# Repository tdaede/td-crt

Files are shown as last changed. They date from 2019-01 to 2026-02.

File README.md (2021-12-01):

# td-crt

This repo contains work-in-progress electronics to control a CRT monitor (aka a CRT chassis).

It is divided up into several separate projects, as follows:

* **[td-deflect](td-deflect/)** - Main PCB, containing microcontroller, horizontal and vertical deflection circuits, RGB amplifier, B+ power supply, 12V and -12V power supplies, and heater power supply. Functional with an enormous amount of rework.

* **[td-hv](td-hv/)** - Regulated HV/focus/screen power supply, based on K7000 clone flyback. Currently marginally functional, demos were done with the original monitor's HV.

* **[td-rgbinput](td-rgbinput/)** - Poorly named RGB amplifier that replaces the version on td-deflect, using more modern parts. Currently untested.

* **[td-180v](td-180v/)** - 180V (and heater) boost converter, designed to be installed on a neck board to provide an optional dedicated power supply for the cathode amplifiers.

* **[td-rgb](td-rgb/)** - Old RGB mod PCB, I should move it to a separate repo at some point.

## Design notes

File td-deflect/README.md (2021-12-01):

**td-deflect** is the primary PCB of td-crt, containing most of the pieces of a complete chassis.

The chassis is a multisync design with separate HV and deflection, allowing arbitrary scan rates, within the voltage and current limits of the ciruit.

RGB input
---------

There is a completely analog RGB path, based on a M51387P RGB amplifier IC. While effective, the chip has been out of production for a long time and therefore the **td-rgbinput** board exists as a future design that eliminates the IC.

Sync processing
---------------

The sync is separated by a LMH1980 sync separator IC. This is responsible for AC coupling the sync input, and separating it into separate H and V syncs (in the case of composite sync). It is also relied on for the back porch output, which is fed in to the clamping circuts, and the odd/even output, which is used for interlacing support.

Horizontal PLL
--------------

There is no analog horizontal PLL - instead, the horizontal sync is fed directly into the timers of the STM32F7. A software PLL is implemented using the internal timers. While this leads to quite robust sync processing, it also results in a minimum PLL jitter of a single clock period of 4.6ns. This is adequate for 15kHz content but not ideal. A future board may use the STM32G4 instead, which has an internal DLL that leads to minimum jitter on the order of 184ps.

Vertical ramp generator
-----------------------

The vertical ramp is generated in software. A software correction is applied for linearity, after which it is output via the stm32's DAC.

Vertical amplifier
------------------

The vertical amplifier is a classic discrete class AB amp, with current feedback (a voltage input corresponds to a current setpoint). The feedback network is fixed in analog components, which turns out not to be flexible enough for all yoke designs. In addition, it does not actually have any AB biasing, instead relying on feedback to avoid crossover distortion, which limits its performance. That said, it's quite effective as is. The amplifer is DC-coupled so that vertical position offsets are simply a DC bias on the input.

One leg of the amplifier is powered by 12V, and the other is powered by 48V in order to provide a faster retrace interval with high inductance yokes.

A planned future design replaces the vertical amplifier with a class D circuit with software feedback, to allow software tuning of the feedback network as well as increased power efficiency, though with the added complexity of dampled RLC output filter design.

Horizontal circuit
------------------

The horizontal circuit is a classic CRT horizontal class-C amplifier, which recovers the energy stored in the yoke for retrace.

The horizontal output transistor is a silicon carbide MOSFET for its very high voltage handling abilities. BJT-based HOTs are still manufactured as a backup option, however SiC MOSFETs are actually cheaper now and offer better performance. In addition, their intrinisic body diode renders an external freewheeling diode unnecessary.

A fixed film cap is used as the retrace timing capacitor.

There is a bank of 4 switchable S-capacitors allowing for 16 total possible S correction values.

There is no E-W correction or horizontal DC bias adjustment.

There is a current sense transformer provided for current feedback, but it is currently untested.

B+ power supply
---------------

The B+ power supply is a 100-200V boost converter to power the horizontal deflection circuits. It is based on a LT3758A asynchronous boost controller and is capable of up to 500mA of output current. It is currently thermally limited and could use a bit of work to increase efficiency and therefore boost the output power.

12V power supply
----------------

There is a 12V buck converter for 12V.

Negative 12V power supply
-----------------

There is a boost topology -12V converter. It currently does not work.

Heater power supply
-------------------

A linear regulator provides a heater power supply. Untested.

HV circuit
----------

Part of an extremely basic HV driver is present on the PCB, but is untested.

Software
--------

The on-board STM32 handles horizontal and vertical deflection, though the rest of the board runs without software intervention. The software is based on the [RTIC](https://rtic.rs) framework and written in Rust. It provides a very primitive serial interface to upload configuration and download runtime statistics. The software is also responsible for implementing all of the self protection logic.

There is a companion desktop GTK4 app with an extremely basic "remote" GUI.

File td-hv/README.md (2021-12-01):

**td-hv** is a HV/EHT driver board. It uses a K7000 clone replacement flyback (053X0528-001).

The circuit is a classic current mode flyback driver circuit based on the UCC3801. The circuit integrates secondary-side feedback by (ab)using the resistive divider created by the focus and screen potentiometers of the flyback, inspired by the drive circuit on the MS-2931 and similar monitors.

The primary drive transistor is a SiC MOSFET which has a sufficiently low gate drive voltage to be driven directly by the 12V gate drive output of the UCC3801.

The circuit free-runs at 14kHz, but can by synchronized to a higher frequency with a sync input pin, which is critical for not having a jittery iamge.

The circuit is currently very unstable. The primary problem is that the enormous amount of leakage inductance and capacitance of the flyback causes very slow ringing of the primary current. If the duty cycle and frequency of the switching circuit turn on the MOSFET while the switching node is at a high voltage (e.g. more than 100V) the sudden amount of current produces a voltage spike that confuses the current mode sensing of the UCC3801. Series LR damping has proven only marginally effective.

There is also an X-Ray protection circuit which provides a redundant shutdown path by measuring the peak voltage off a tertiary winding of the flyback.

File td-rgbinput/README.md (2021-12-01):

**td-rgbinput** is a replacement RGB analog path, providing the color controls between the RGB input and the final amplification stage on the neck board of the CRT.

Most consumer sets use an integrated RGB amplification IC, however none of these are still in production. Thus, this PCB was designed to instead use modern discrete amplifier components.

The primary challenge of the board is providing the global gain control across all 3 channels. This requires a voltage controlled amplifier, which is a difficult circuit to create when cross channel matching is desired.

The first stage of the input is AC coupling followed by a dc restore circuit, implemented as a clamp to ground. This is less accurate than a dc restore based on an op amp adder, but super simple to implement.

Next, the global gain control is applied via an AD8337 voltage controlled amplifier. The global gain voltage is divided by a per-channel gain adjustment before being fed into the AD8337's gain input.

Following this, a global and per-channel bias is applied via a resistor adder. The global bias voltage is carefully buffered to avoid compromising the high frequency response of the circut. In addition, a blanking input can pull the output voltage down to zero at this stage.

Finally, an amplfiication stage based on the ADA4861 provides a fixed 2x gain, and more importantly, higher current to the output. The outputs include a series 47 ohm resistor with the assumption that they will go directly to the base of transistors on the neck board.

The circuit also has a local 5V supply, -5V supply, and a blank OR-ing circuit for convenience. Termination can be enabled or disabled via a bank of DIP switches.

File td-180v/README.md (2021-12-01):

td-180v is a power supply designed to bolt on the back of a Nanao MS9 neck board and provide the cathode amplifier and heater voltages, independent of the B+ regulation of the main PCB. It also provides an optional linear regulator for the heater.

It is a simple asynchronous boost converter design based on the (relatively expensive) LT3758A. It is powered by the B+ rail input, and also requires a +12V rail for logic. As a result it can only regulate to voltages higher than B+.

The current design is too noisy for practical use.

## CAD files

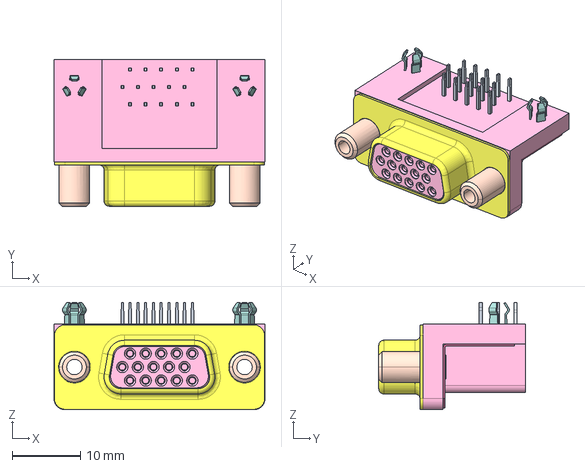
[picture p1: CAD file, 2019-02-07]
td-rgb/amphenol/iicd15s13e6gv00lf.igs
31.0 x 21.6 x 15.8 mm

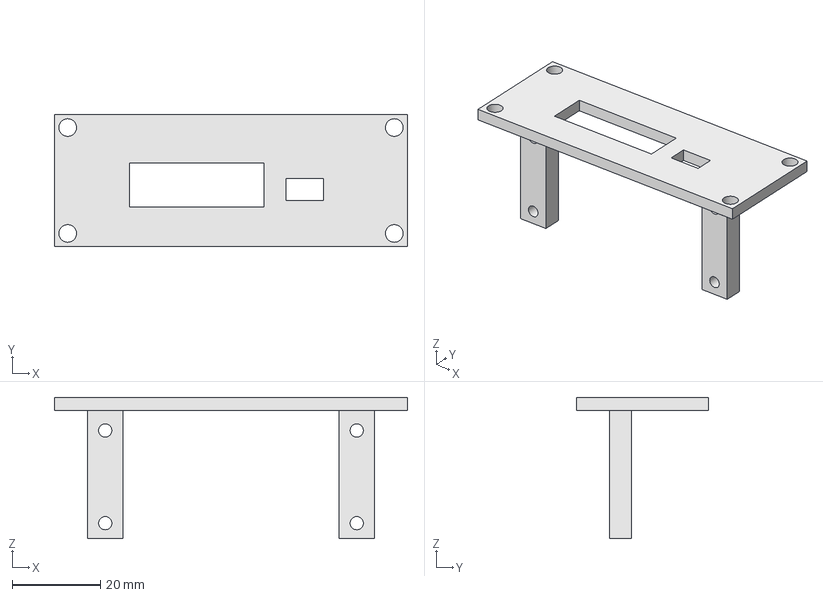
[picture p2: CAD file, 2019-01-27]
td-rgb/td-rgb-bracket.fcstd
80.0 x 30.0 x 32.0 mm

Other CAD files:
td-rgb/td-rgb-bracket.stl

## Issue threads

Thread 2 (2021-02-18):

I can't open the td-deflect.kicad_pcb with kicad 5.1.9

maxxsun, 2021-02-18:
I can't open the td-deflect.kicad_pcb with kicad 5.1.9 .

tdaede, 2021-08-14:
You need KiCad nightly to open it.

(the other PCBs use stable)

Closed 2021-08-14.

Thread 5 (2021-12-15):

Can this drive a JVC bubble tube A68ADT25X01?

chuckhacker, 2021-12-15:
JVC’s curved bubble tube, the A68ADT25X01, was used for 10 years throughout their consumer TV lines.

The tube was used so long by JVC because of its great design. Even TVs from 20 years ago have no geometry issues and very minor focus issues. The quality is superb. At this point, it is easier to come across the tube than an actual D-Series TV, as prices continue to inflate.

So if it's possible to come up with an open source driver board for this CRT tube, it would certainly fill a niche for enthusiasts like myself.

tdaede, 2021-12-18:
Yes, it should be able to. That tube (and the equivalent Toshiba models used for MS8/MS9 etc) should work well. The circuit is designed to use the original yoke, so if the yoke is bonded it should still be OK.

Depending on the particular inductance of the yoke, higher scan rates (24-31kHz) can be more difficult, though if it's not more than the ~2mH that most of these are it should be OK.

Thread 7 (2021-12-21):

Can this drive Phillips A59EAK552X21 ?

oomek, 2021-12-21:
It's a tube used in Bang & Olufsen Beovision 1 consumer TV. It has no convergence rings and 6 pin yoke.
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

oomek, 2021-12-21:
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

tdaede, 2021-12-21:
That looks pretty typical. It can't currently drive the rotation coil so you won't have rotation adjustment.

The neck board transistors look surprisingly small. Is a service manual available?

oomek, 2021-12-22:
Oh, so this 2 wires aren't required to drive the yoke, just are responsible for rotation? I don't have any schematic, just manual which is'n very helpful. I could make some more photos of the transistors.

riggles1, 2022-07-14:
Great to know, as LG.Philips are very common here in Europe, used my multiple brands and arcade machines using these tubes as well. Usually these yokes have an electromagnetic convergence piece, and the tube themselves have dual focus (dual focus tubes are pretty much the norm in Europe regardless of manufacturer for 25-29" (A59-A66) tube sizes).

Relieving to know these won't be problematic, with how common they are in these regions.

oomek, 2022-07-14:
Update: I've opened today another Beovision1, an older SW 1.2 version and it has only 4 wires connected to the deflection coils. Red and Brown are NC.

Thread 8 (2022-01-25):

A question about the 2N7002NXBKR Trench MOSFET

soniccd123, 2022-01-25:
Hello friend,

Great project, looking forward to the next developments, would love to use some of it in one of my TVs someday

I have a question. For the last year and a half i've been working on a Panasonic TC-14RM15L as a test bed for some modifications with the objective of creating a adequate and safe way to add RGB inputs to non European CRT TVs. There are ways to do it in older TVs that have the Jungle IC separated from the TV MCU, but most modern CRTs do not have this configuration.

One area that I'm having trouble is the HBlanking on this set, without correct color signal atenuation, lots of regularly timed transversal lines are visible on the screen. These lines seem to be the beam returning to draw the next line. The problem is that some devices, like the Sega Dreamcast, in specific video modes, will display these lines even with the needed atenuation. Looking at you schematics I supose that I need to pull each color signal low every blank interval and maybe these lines will disapear. I'm excited to try your solution (from what i could understand in the schematics), but I need to know if the 2N7002NXBKR is strictly necessary or one could use more acessible alternatives like the 2N7002L.

Thank you very much, good work!

tdaede, 2022-01-25:
Hi,

Yes, you can use a plain old 2N7002. The exact one I used is just a particular manufacturer's model that I chose at the time based on availability.

There are two RGB circuits in this repo - one is on td-deflect, and one is in td-rgbinput. The td-deflect one is older and works well, but uses an old stock IC. The td-rgbinput one is functionally similar but built with discrete components.

The td-rgbinput circuit has 4 separate functionalities - a DC restore circuit for AC coupled inputs, a blanking circiut, a gain control circuit, and a bias circuit. You might not need all these parts depending on where you're inserting the signal.

soniccd123, 2022-01-25:
I'm gonna take a look and try to implement them to test, I'm connecting directly to the neckboard of the TV, more specifically, to the video output amplifier that drives the cathodes (TDA6107AJFN1), i'm connecting just the RGB signals to it and letting the TV's circuitry take charge of the Sync. Between the neckboard and the device I've added some simple circuitry to control the signals, but not nearly as elegant as your aproach. It works quite well, this TV actually became my main way to play old video games, but I think that its possible to make it even better adapting your designs to it.

Do you recommend any resources to learn more about TVs and analog electronics? While i've been playing around with this TV, i lack a lot of the knowledge to really understand deeply how all of these parts work

tdaede, 2022-01-25:
The neck board on that TV actually has a blanking input, I think. If you
supply an appropriately timed blanking signal (might even just be able to
use the sync signal to start with) you should be able to make it blank.

Unfortunately a lot of this knowledge is pre-internet. I'd recommend Sam's
FAQs to start:

https://www.repairfaq.org/sam/tvfaq.htm
https://www.repairfaq.org/sam/monfaq.htm
https://www.repairfaq.org/sam/crtfaq.htm
https://www.repairfaq.org/sam/deflfaq.htm

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

soniccd123, 2022-01-26:
Thanks for the resources, it is quite hard indeed to find these things on internet

Was taking a look at the TV service manual, unfortunately the neck board doesn't seem to have a blanking input, it does have a AKB output from the video amplifier that drives the cathodes, but I suspect to me that the blanking is done on the MCU/Jungle chip before this step (TDA11115NDS, a chip which not datasheet could be found).

I took a look at the td-deflect board and saw that you used a M51387P as video amplifier which i found pretty interesting, not that I didn't like your discrete aproach, but the M51387P seems to be quite cheap where I live. This amplifier is suposed to be used to drive tube directly? In the case of my TV that uses a TDA6107AJFN1 to drive the tube, should the M51387P outputs drive this amplifier or the tube directly?

tdaede, 2022-01-26:
The outputs should drive the amplifier.

I think that the AKB signal is actually an input to the amplifier, not an output.

soniccd123, 2022-01-27:
Are you sure? I found the amplifier datasheet, from what I understood, AKB is connected to the amplifier pin 5 which is a "black-current measurement output" in the datasheet words. It would be very helpful if it was the blank signal input.

tdaede, 2022-01-27:
No, not sure. Didn't realize a monitor like this would bother measuring that, but I suppose it could.

soniccd123, 2022-03-16:
Hey, the M51387P finally arrived, i'm taking a look at the TV schematics and signals, having a hard time to find how to extract the blanking signal from sync. I see that it is very similar to H-sync, can i use it or do i need another solution?

tdaede, 2022-06-27:
Yes, you can use H-sync to blank. However, clamping needs to not intersect with blanking - it needs to happen after blanking.

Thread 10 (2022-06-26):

Suggestions for someone who wants to try this project

8lall0, 2022-06-26:
Hi,
i have a perfect trinitron that i can "sacrifice" to test this project. How can i start with it? Is there a bom and pcbs?

Thanks!

8lall0, 2022-06-29:
@tdaede oh ok, thank you! :)
I hope this project will continue, it's so interesting.

Closing the issue :)

Closed 2022-06-29.

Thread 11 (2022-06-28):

Question- drivable tubes

michaellarson1000, 2022-06-28:
Would it be possible to drive tubes such as vga monitor tubes or hd crt 1080i tubes with this board, given that suitable parts are used?

tdaede, 2022-07-06:
I can't make any guarantees right now. It will work on trinitrons with appropriate wiring. The main difficulty is the yoke inductance and deflection sensitivity, which you can't know without getting the tube. There are workarounds even if it isn't ideal.

Numbski, 2022-07-06:
Oh, by all means - not looking for any kind of guarantee, and this is all very much WIP.

My question was more one of "am I even barking up a feasible tree"?

It sounds as though "yes, it might be, but we have no certainty".

I will see if I can run down a service manual and figure out what tube is in play on this one in particular.  Last I can do to put this to bed, but this does add a small amount of clarity.

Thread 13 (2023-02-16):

voltages for contrast and brightness SW controlled?

gcopoix, 2023-02-16:
Hi, what about controlling the voltages for contrast and brightness by e.g. an 8ch I2C/SPI DAC?
Would have several advantages in my opinion:
- less effort for populating the PCB
- less footprint, smaller PCB
- could  lead to better profiles for known CRTs
- all SW controllable (without disassembling the Monitor/TV)
- cheaper (e.g. an DAC088S085 is around 3...4 USD) ?

The other resistors for voltage control could be handled this way too, or by a digital poti ?

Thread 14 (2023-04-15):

Can you generate schematic pdf

boilerbots, 2023-04-15:
It would be nice if you generated a PDF of the schematics when you upload the project. That would make it easy for people to look at without the hassle of KiCad. I am curios to take a look at your design, I have been working on driving electrostatic CRTs for vector clocks with modern HV MOSFETs and switching power supplies.

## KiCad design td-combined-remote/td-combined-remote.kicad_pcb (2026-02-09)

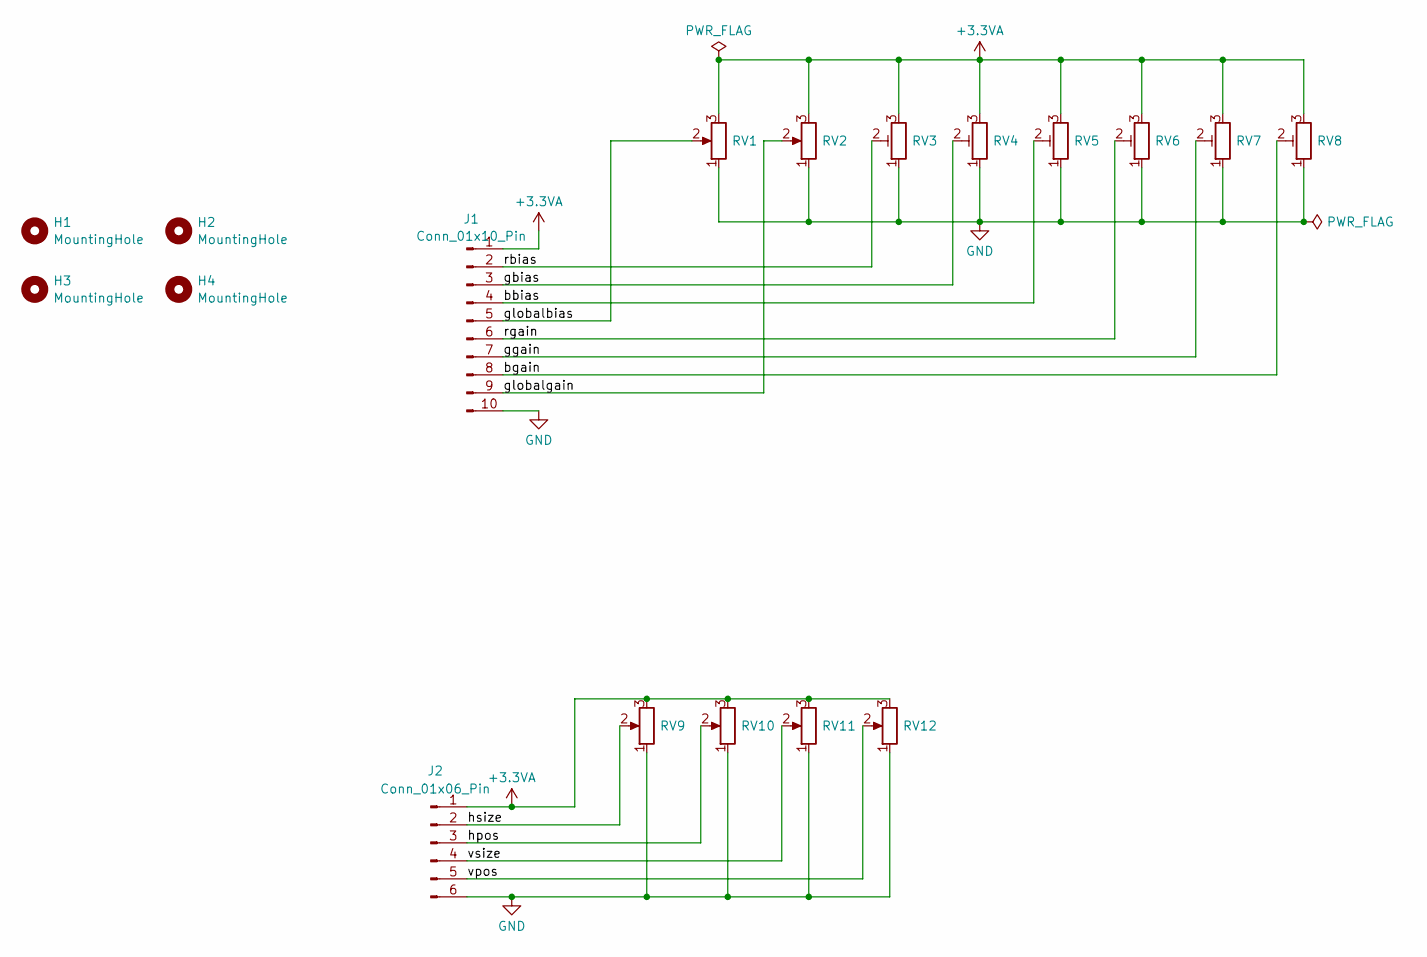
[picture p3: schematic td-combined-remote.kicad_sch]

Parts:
H1, H2, H3, H4: MountingHole; MountingHole_3.2mm_M3
J1: Conn_01x10_Pin; JST_XH_S10B-XH-A_1x10_P2.50mm_Horizontal; Digikey 455-S10B-XH-A-ND
J2: Conn_01x06_Pin; JST_XH_S6B-XH-A_1x06_P2.50mm_Horizontal; Digikey 455-S6B-XH-A-ND
RV1, RV2, RV9, RV10, RV11, RV12: R_Potentiometer; Potentiometer_Alps_RK09K_Single_Vertical; Digikey PTV09A-4015U-B103-ND
RV3, RV4, RV5, RV6, RV7, RV8: R_Potentiometer_Trim; Potentiometer_Bourns_3386P_Vertical; Digikey 3386P-103TLF-ND

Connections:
+3.3VA: J1.1, J2.1, RV1.3, RV2.3, RV3.3, RV4.3, RV5.3, RV6.3, RV7.3, RV8.3, RV9.3, RV10.3, RV11.3, RV12.3
/bbias: J1.4, RV5.2
/bgain: J1.8, RV8.2
/gbias: J1.3, RV4.2
/ggain: J1.7, RV7.2
/globalbias: J1.5, RV1.2
/globalgain: J1.9, RV2.2
/hpos: J2.3, RV10.2
/hsize: J2.2, RV9.2
/rbias: J1.2, RV3.2
/rgain: J1.6, RV6.2
/vpos: J2.5, RV12.2
/vsize: J2.4, RV11.2
GND: J1.10, J2.6, RV1.1, RV2.1, RV3.1, RV4.1, RV5.1, RV6.1, RV7.1, RV8.1, RV9.1, RV10.1, RV11.1, RV12.1

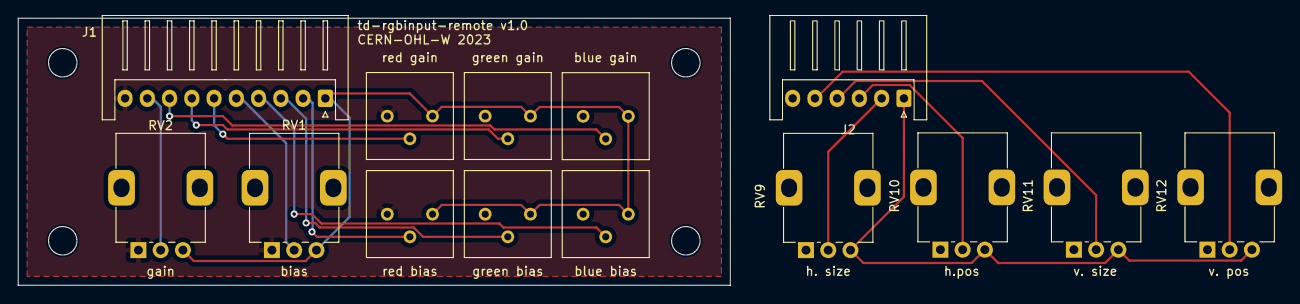
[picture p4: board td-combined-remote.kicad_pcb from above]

Board: 2 copper layers, 80.0 x 30.0 mm, 18 parts (0 on the bottom side), 14 nets.

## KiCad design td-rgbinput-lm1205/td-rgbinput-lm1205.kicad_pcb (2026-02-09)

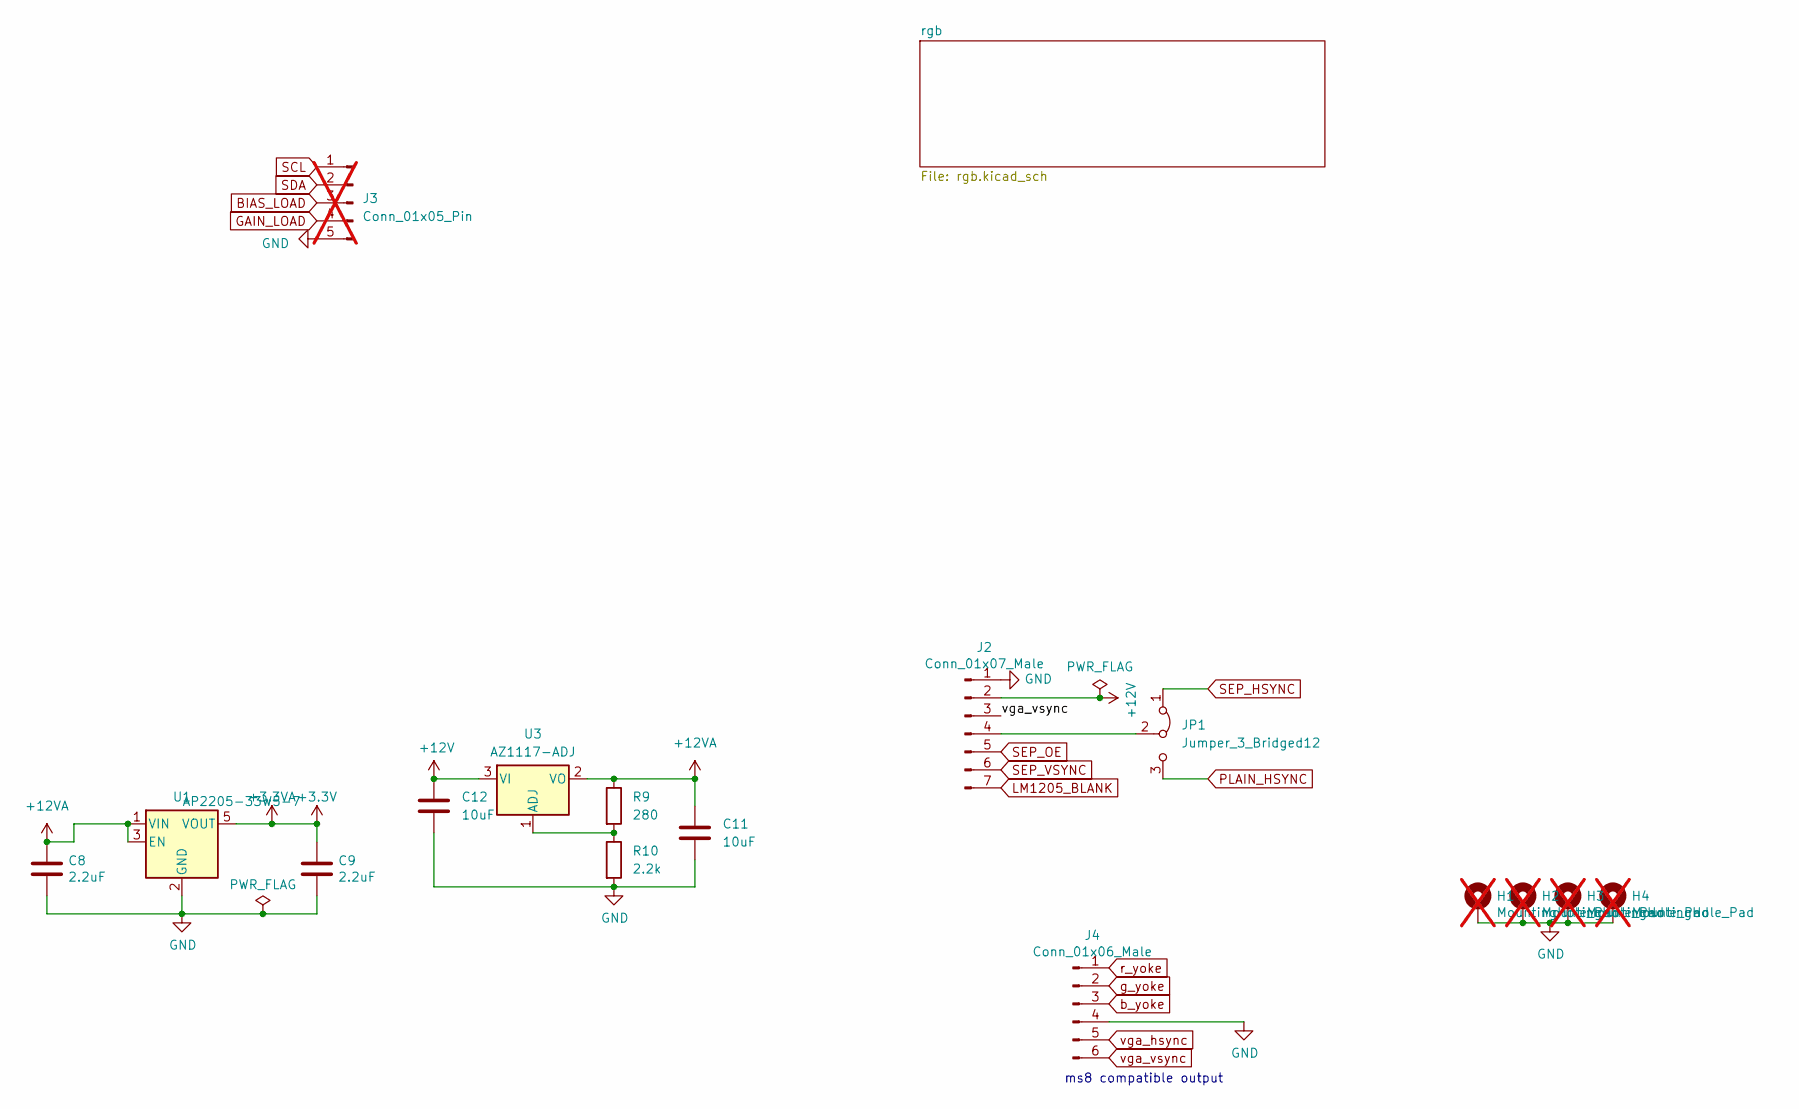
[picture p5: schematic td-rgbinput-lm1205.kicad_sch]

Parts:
C8, C9: 2.2uF; C_0805_2012Metric; Digikey 490-14467-1-ND
C11, C12: 10uF; C_0805_2012Metric
H1, H2, H3, H4: MountingHole_Pad; MountingHole_3.2mm_M3_Pad_Via; not fitted
J2: Conn_01x07_Male; JST_XH_B7B-XH-A_1x07_P2.50mm_Vertical; Digikey 1175-51025-07-0100-01-ND
J3: Conn_01x05_Pin; JST_XH_B5B-XH-A_1x05_P2.50mm_Vertical; Digikey B5B-XH-A; not fitted
J4: Conn_01x06_Male; JST_EH_B6B-EH-A_1x06_P2.50mm_Vertical; Digikey 455-1615-ND
JP1: Jumper_3_Bridged12; PinHeader_1x03_P2.54mm_Vertical
R9: 280; R_0805_2012Metric; Digikey 311-280CRCT-ND
R10: 2.2k; R_0805_2012Metric; Digikey 311-2.2KCRCT-ND
U1: AP2205-33W5-7; SOT-23-5; Digikey 31-AP2205-33W5-7CT-ND
U3: AZ1117-ADJ; SOT-223-3_TabPin2

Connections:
+3.3V: C9.1, U1.5 (VOUT); also elsewhere on the board
+12V: C12.1, J2.2, U3.3 (VI)
+12VA: C8.1, C11.1, R9.1, U1.1 (VIN), U1.3 (EN), U3.2 (VO); also elsewhere on the board
BIAS_LOAD: J3.3; also elsewhere on the board
GAIN_LOAD: J3.4; also elsewhere on the board
GND: C8.2, C9.2, C11.2, C12.2, H1.1, H2.1, H3.1, H4.1, J2.1, J3.5, J4.4, R10.2, U1.2 (GND); also elsewhere on the board
LM1205_BLANK: J2.7; also elsewhere on the board
unnamed: J2.4, JP1.2 (C)
unnamed: R9.2, R10.1, U3.1 (ADJ)
PLAIN_HSYNC: JP1.3 (B); also elsewhere on the board
SCL: J3.1; also elsewhere on the board
SDA: J3.2; also elsewhere on the board
SEP_HSYNC: JP1.1 (A); also elsewhere on the board
SEP_OE: J2.5; also elsewhere on the board
SEP_VSYNC: J2.6; also elsewhere on the board
b_yoke: J4.3; also elsewhere on the board
g_yoke: J4.2; also elsewhere on the board
r_yoke: J4.1; also elsewhere on the board
vga_hsync: J4.5; also elsewhere on the board
vga_vsync: J2.3, J4.6; also elsewhere on the board

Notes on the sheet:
ms8 compatible output

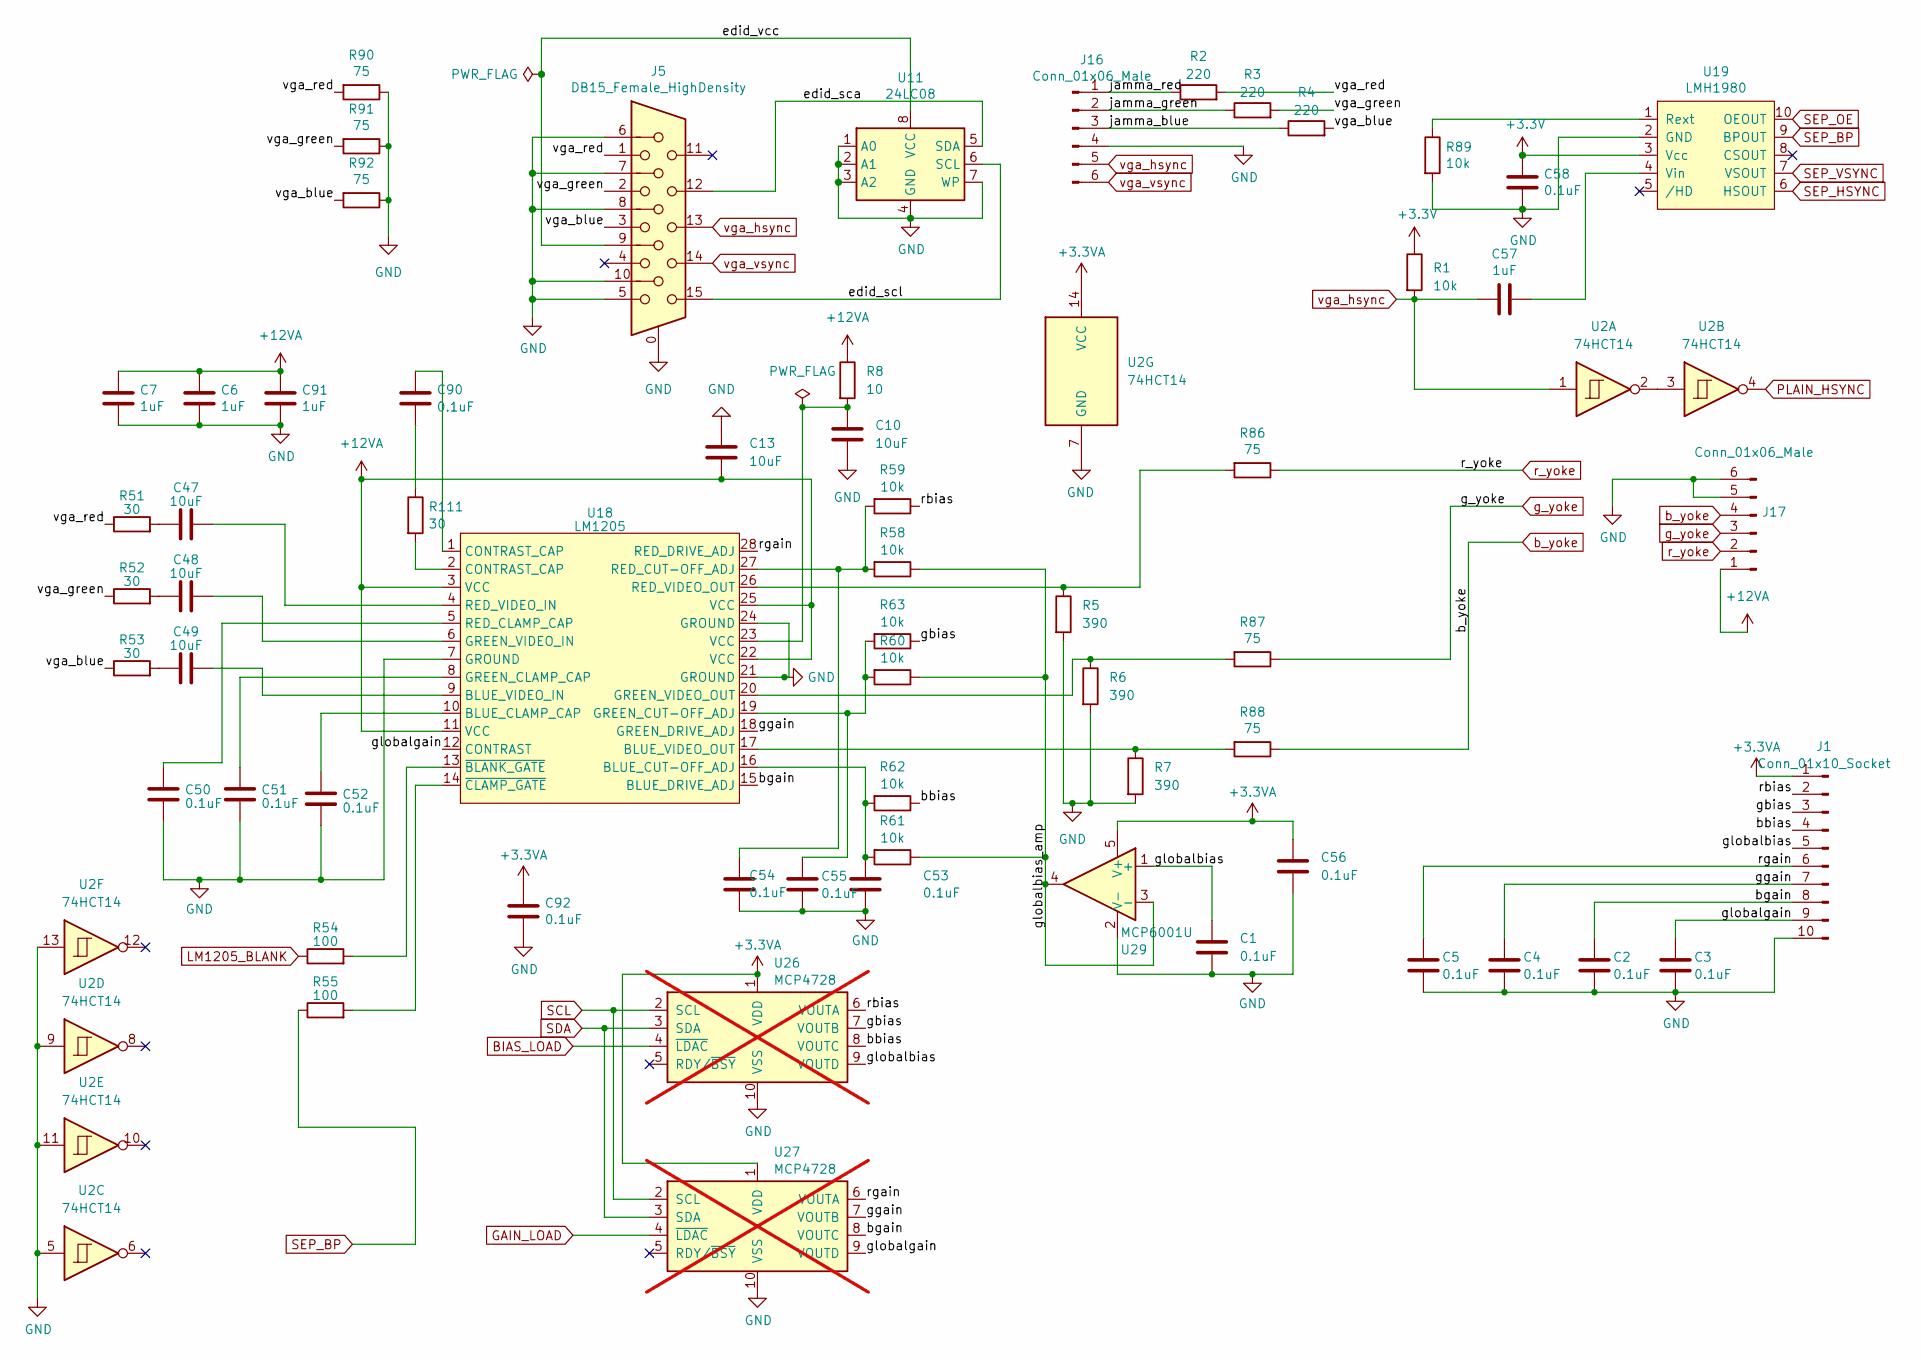
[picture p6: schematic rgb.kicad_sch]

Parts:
C1, C2, C3, C4, C5, C50, C51, C52, C53, C54, C55, C56, C58, C90, C92: 0.1uF; C_0805_2012Metric; Digikey 1276-1099-1-ND
C6, C7, C91: 1uF; C_0805_2012Metric; Digikey 1276-1066-1-ND
C10, C13: 10uF; C_0805_2012Metric
C47, C48, C49: 10uF; C_0805_2012Metric; Digikey 490-10516-1-ND
C57: 1uF; C_0805_2012Metric; Voltage 25V; Digikey 1276-1066-1-ND
J1: Conn_01x10_Socket; JST_XH_B10B-XH-A_1x10_P2.50mm_Vertical; Digikey 455-B10B-XH-A-ND
J5: DB15_Female_HighDensity; DSUB-15-HD_Socket_Horizontal_P2.29x2.54mm_EdgePinOffset8.35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; Digikey AE11024-ND
J16: Conn_01x06_Male; JST_EH_B6B-EH-A_1x06_P2.50mm_Vertical; Digikey 455-1615-ND
J17: Conn_01x06_Male; JST_XH_B6B-XH-A_1x06_P2.50mm_Vertical; Digikey 455-2271-ND
R1, R58, R59, R60, R61, R62, R63, R89: 10k; R_0805_2012Metric; Digikey 311-1.00KCRCT-ND
R2, R3, R4: 220; R_0805_2012Metric; Digikey 311-220CRCT-ND
R5, R6, R7: 390; R_0805_2012Metric
R8: 10; R_0805_2012Metric
R51, R52, R53, R111: 30; R_0805_2012Metric; Digikey 311-30.0CRCT-ND
R54, R55: 100; R_0805_2012Metric; Digikey 311-100CRCT-ND
R86, R87, R88, R90, R91, R92: 75; R_0805_2012Metric; Digikey 311-75.0CRCT-ND
U2: 74HCT14; SOIC-14_3.9x8.7mm_P1.27mm; Digikey 74HCT14S14-13DICT-ND
U11: 24LC08; SOIC-8_3.9x4.9mm_P1.27mm; Digikey 24LC08BT/SNCT-ND
U18: LM1205; DIP-28_W15.24mm
U19: LMH1980; VSSOP-10_3x3mm_P0.5mm; Digikey LMH1980MM/NOPBCT-ND
U26, U27: MCP4728; MSOP-10_3x3mm_P0.5mm; Digikey MCP4728T-E/UNCT-ND; not fitted
U29: MCP6001U; SOT-23-5; Digikey MCP6001UT-I/OTCT-ND

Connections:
+3.3V: C56.1, C58.1, C92.1, J1.1, R1.1, U2.14 (VCC), U19.3 (Vcc), U26.1 (VDD), U27.1 (VDD), U29.5 (V+); also elsewhere on the board
+12VA: C6.1, C7.1, C13.1, C91.1, J17.1, R8.1, U18.3 (VCC), U18.11 (VCC), U18.22 (VCC), U18.25 (VCC); also elsewhere on the board
/rgb/bbias: J1.4, R62.1, U26.8 (VOUTC)
/rgb/bgain: C2.1, J1.8, U18.15 (BLUE_DRIVE_ADJ), U27.8 (VOUTC)
/rgb/edid_sca: J5.12, U11.5 (SDA)
/rgb/edid_scl: J5.15, U11.6 (SCL)
/rgb/edid_vcc: J5.9, U11.8 (VCC)
/rgb/gbias: J1.3, R63.1, U26.7 (VOUTB)
/rgb/ggain: C4.1, J1.7, U18.18 (GREEN_DRIVE_ADJ), U27.7 (VOUTB)
/rgb/globalbias: C1.1, J1.5, U26.9 (VOUTD), U29.1 (+)
/rgb/globalbias_amp: R58.1, R60.1, R61.1, U29.3 (-), U29.4
/rgb/globalgain: C3.1, J1.9, U18.12 (CONTRAST), U27.9 (VOUTD)
/rgb/jamma_blue: J16.3, R4.1
/rgb/jamma_green: J16.2, R3.1
/rgb/jamma_red: J16.1, R2.1
/rgb/rbias: J1.2, R59.1, U26.6 (VOUTA)
/rgb/rgain: C5.1, J1.6, U18.28 (RED_DRIVE_ADJ), U27.6 (VOUTA)
/rgb/vga_blue: J5.3, R4.2, R53.1, R92.2
/rgb/vga_green: J5.2, R3.2, R52.1, R91.2
/rgb/vga_red: J5.1, R2.2, R51.1, R90.2
BIAS_LOAD: U26.4 (~LDAC); also elsewhere on the board
GAIN_LOAD: U27.4 (~LDAC); also elsewhere on the board
GND: C1.2, C2.2, C3.2, C4.2, C5.2, C6.2, C7.2, C10.2, C13.2, C50.1, C51.1, C52.1, C53.2, C54.2, C55.2, C56.2, C58.2, C91.2, C92.2, J1.10, J5.0, J5.5, J5.6, J5.7, J5.8, J5.10, J16.4, J17.5, J17.6, R5.2, R6.2, R7.2, R89.2, R90.1, R91.1, R92.1, U2.5, U2.7 (GND), U2.9, U2.11, U2.13, U11.1 (A0), U11.2 (A1), U11.3 (A2), U11.4 (GND), U11.7 (WP), U18.7 (GROUND), U18.21 (GROUND), U18.24 (GROUND), U19.2 (GND), U26.10 (VSS), U27.10 (VSS), U29.2 (V-); also elsewhere on the board
LM1205_BLANK: R54.1; also elsewhere on the board
unnamed: C10.1, R8.2, U18.23 (VCC)
unnamed: C47.1, R51.2
unnamed: C48.1, R52.2
unnamed: C49.1, R53.2
unnamed: C90.1, U18.1 (CONTRAST_CAP)
unnamed: C90.2, R111.1
unnamed: R111.2, U18.2 (CONTRAST_CAP)
unnamed: U2.2, U2.3
unnamed: C52.2, U18.10 (BLUE_CLAMP_CAP)
unnamed: C53.1, R61.2, R62.2, U18.16 (BLUE_CUT-OFF_ADJ)
unnamed: C49.2, U18.9 (BLUE_VIDEO_IN)
unnamed: R7.1, R88.2, U18.17 (BLUE_VIDEO_OUT)
unnamed: C51.2, U18.8 (GREEN_CLAMP_CAP)
unnamed: C55.1, R60.2, R63.2, U18.19 (GREEN_CUT-OFF_ADJ)
unnamed: C48.2, U18.6 (GREEN_VIDEO_IN)
unnamed: R6.1, R87.2, U18.20 (GREEN_VIDEO_OUT)
unnamed: C50.2, U18.5 (RED_CLAMP_CAP)
unnamed: C54.1, R58.2, R59.2, U18.27 (RED_CUT-OFF_ADJ)
unnamed: C47.2, U18.4 (RED_VIDEO_IN)
unnamed: R5.1, R86.2, U18.26 (RED_VIDEO_OUT)
unnamed: R54.2, U18.13 (~BLANK_GATE)
unnamed: R55.2, U18.14 (~CLAMP_GATE)
unnamed: R89.1, U19.1 (Rext)
unnamed: C57.1, U19.4 (Vin)
PLAIN_HSYNC: U2.4; also elsewhere on the board
SCL: U26.2 (SCL), U27.2 (SCL); also elsewhere on the board
SDA: U26.3 (SDA), U27.3 (SDA); also elsewhere on the board
SEP_BP: R55.1, U19.9 (BPOUT)
SEP_HSYNC: U19.6 (HSOUT); also elsewhere on the board
SEP_OE: U19.10 (OEOUT); also elsewhere on the board
SEP_VSYNC: U19.7 (VSOUT); also elsewhere on the board
b_yoke: J17.4, R88.1; also elsewhere on the board
g_yoke: J17.3, R87.1; also elsewhere on the board
r_yoke: J17.2, R86.1; also elsewhere on the board
vga_hsync: C57.2, J5.13, J16.5, R1.2, U2.1; also elsewhere on the board
vga_vsync: J5.14, J16.6; also elsewhere on the board

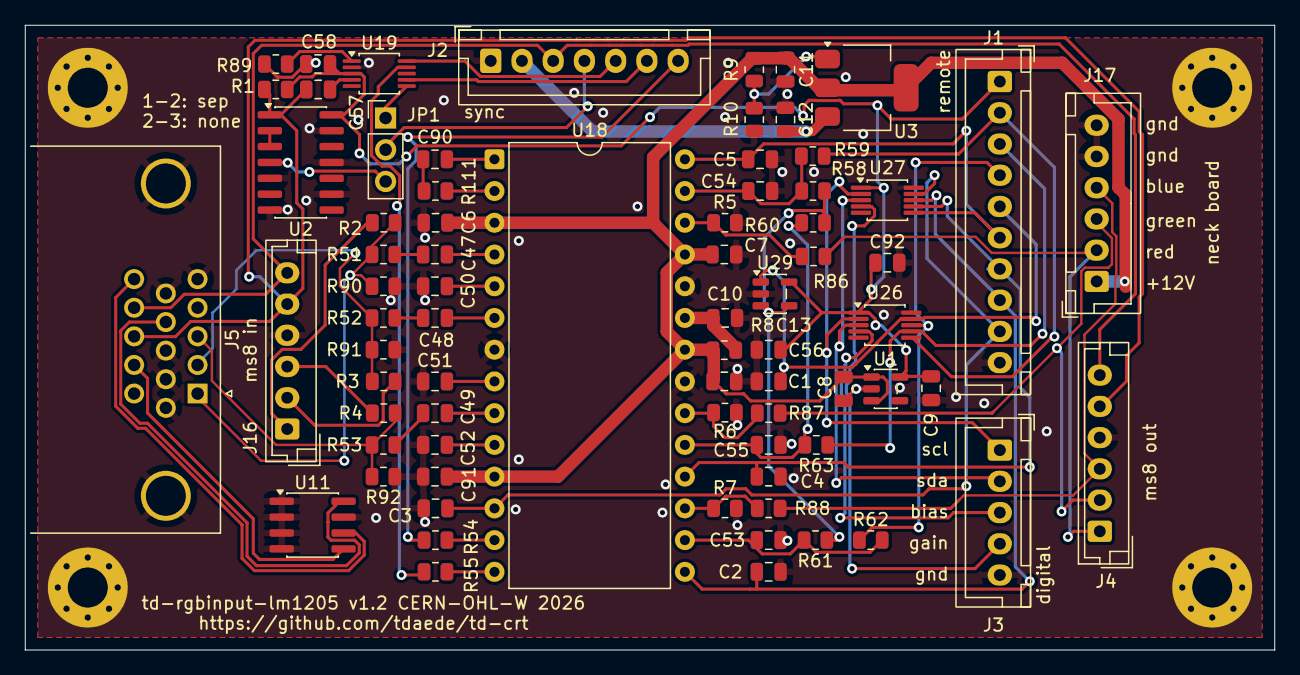
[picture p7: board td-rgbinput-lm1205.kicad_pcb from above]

Board: 2 copper layers, 100.0 x 50.0 mm, 78 parts (0 on the bottom side), 63 nets.

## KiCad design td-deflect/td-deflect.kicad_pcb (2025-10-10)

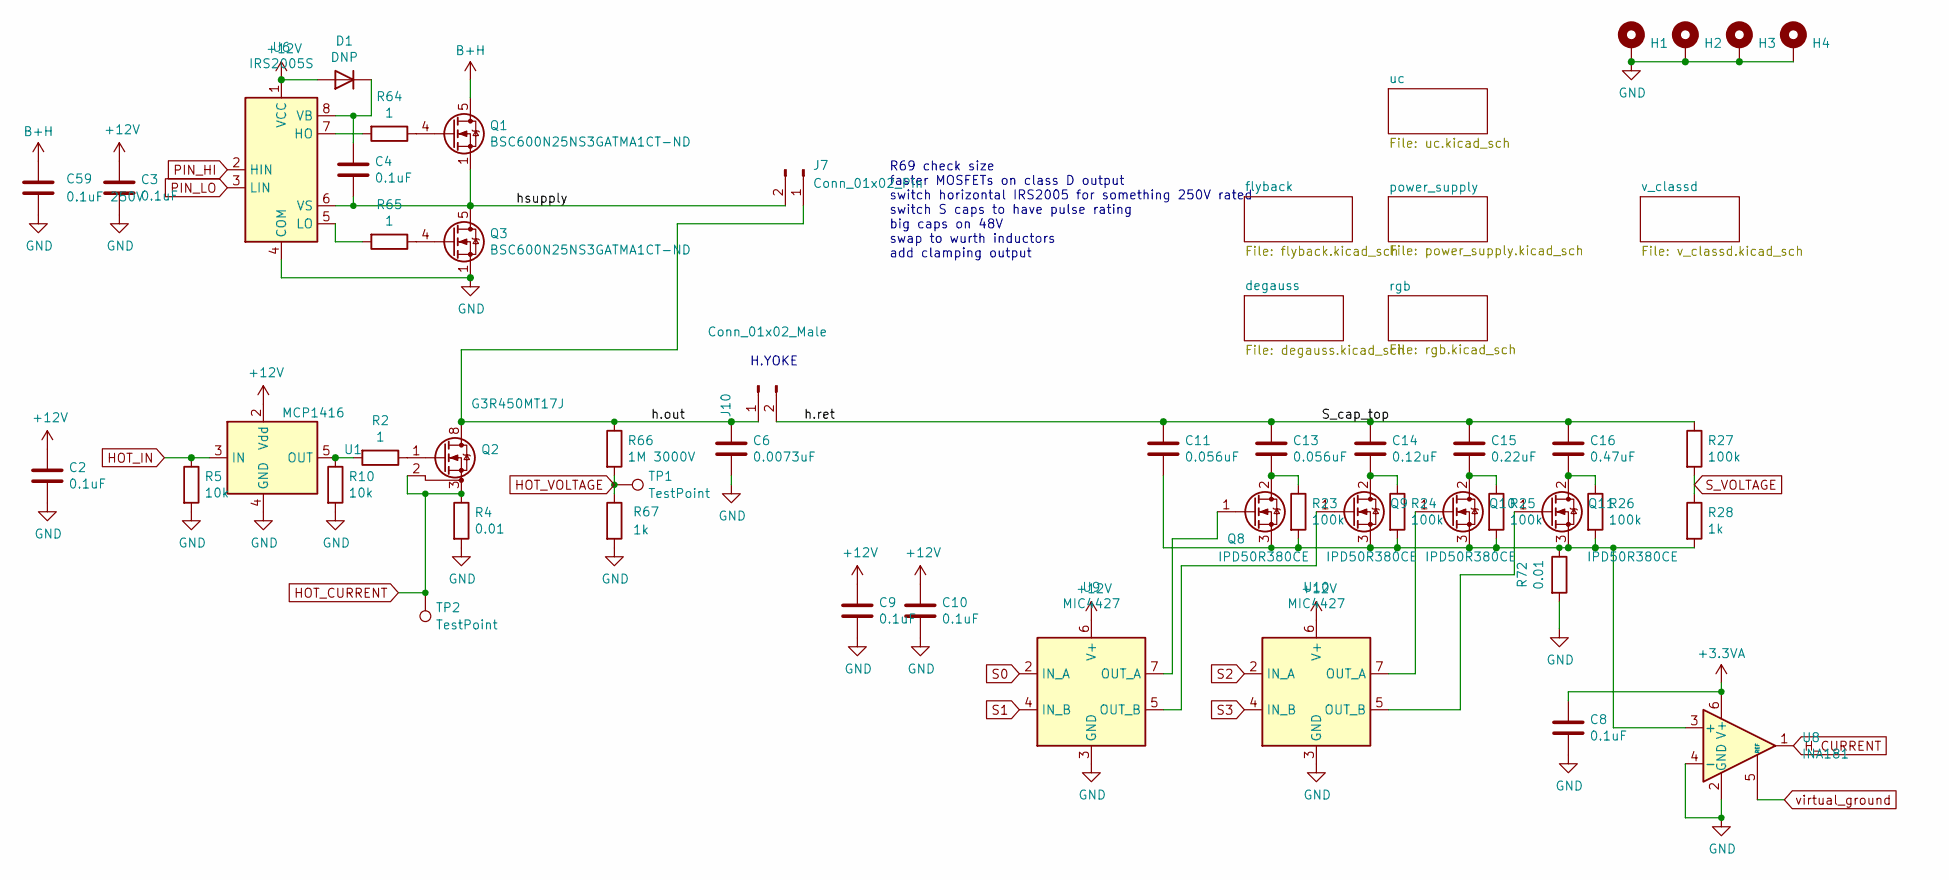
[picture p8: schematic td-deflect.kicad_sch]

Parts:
C2, C3, C4: 0.1uF; C_0805_2012Metric_Pad1.18x1.45mm_HandSolder; Digikey 311-1140-1-ND
C6: 0.0073uF; C_Rect_L18.0mm_W6.0mm_P15.00mm_FKS3_FKP3; Voltage 2000V; Digikey 495-3231-ND
C8, C9, C10: 0.1uF; C_0805_2012Metric_Pad1.18x1.45mm_HandSolder; Voltage 10V; Digikey 311-1140-1-ND
C11, C13: 0.056uF; C_Rect_L18.0mm_W5.0mm_P15.00mm_FKS3_FKP3; Voltage 250V; Digikey 732-5795-ND
C14: 0.12uF; C_Rect_L18.0mm_W8.0mm_P15.00mm_FKS3_FKP3; Voltage 250V; Digikey 732-5799-ND
C15: 0.22uF; C_Rect_L18.0mm_W6.0mm_P15.00mm_FKS3_FKP3; Voltage 250V; Digikey 732-5802-ND
C16: 0.47uF; C_Rect_L18.0mm_W8.0mm_P15.00mm_FKS3_FKP3; Voltage 250V; Digikey 732-5805-ND
C59: 0.1uF 250V; C_1206_3216Metric; Digikey 445-8899-1-ND
D1: DNP; D_SOD-123; Digikey ES1G-FDICT-ND
H1, H2, H3, H4: MountingHole_Pad; MountingHole_3.2mm_M3_Pad_Via; Digikey DNP
J7: Conn_01x02_Pin; monitor_10_8_2p
J10: Conn_01x02_Male; monitor_10_8_2p; Digikey DNP
Q1, Q3: BSC600N25NS3GATMA1CT-ND; TDSON-8-1; Digikey BSC600N25NS3GATMA1CT-ND
Q2: G3R450MT17J; TO-263-7_TabPin8_GeneSiC; Digikey 1242-G3R450MT17J-TRCT-ND
Q8, Q9, Q10, Q11: IPD50R380CE; TO-252-2; Digikey IPD50R380CEAUMA1CT-ND
R2, R64, R65: 1; R_0805_2012Metric_Pad1.20x1.40mm_HandSolder; Digikey 311-1.00CRCT-ND
R4, R72: 0.01; R_0805_2012Metric_Pad1.20x1.40mm_HandSolder; Digikey 311-0.01NUCT-ND
R5, R10: 10k; R_0805_2012Metric_Pad1.20x1.40mm_HandSolder; Digikey 311-10.0KCRCT-ND
R23, R24, R25, R26: 100k; R_1206_3216Metric_Pad1.30x1.75mm_HandSolder; Digikey 311-100KFRCT-ND
R27: 100k; R_1206_3216Metric_Pad1.30x1.75mm_HandSolder; Voltage 200V; Digikey 311-100KFRCT-ND
R28: 1k; R_1206_3216Metric_Pad1.30x1.75mm_HandSolder; Voltage 200V; Digikey 311-1.00KFRCT-ND
R66: 1M 3000V; R_2512_6332Metric; Digikey CHV2512-FX-1004ELFCT-ND
R67: 1k; R_0805_2012Metric_Pad1.20x1.40mm_HandSolder; Digikey 311-1.00KCRCT-ND
TP1, TP2: TestPoint; TestPoint_Keystone_5015_Micro_Mini; Digikey 36-5015CT-ND
U1: MCP1416; SOT-23-5; Digikey MCP1416T-E/OTCT-ND
U6: IRS2005S; SOIC-8_3.9x4.9mm_P1.27mm; Digikey IRS2005STRPBFCT-ND
U8: INA181; SOT-23-6; Digikey 296-47658-1-ND
U9, U10: MIC4427; SOIC-8_3.9x4.9mm_P1.27mm; Digikey 576-1525-5-ND

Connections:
+3.3VA: C8.1, U8.6 (V+); also elsewhere on the board
+12V: C2.1, C3.1, C9.1, C10.1, D1.2 (A), U1.2 (Vdd), U6.1 (VCC), U9.6 (V+), U10.6 (V+); also elsewhere on the board
/S_cap_top: C11.1, C13.1, C14.1, C15.1, C16.1, J10.2, R27.1
/h.out: C6.1, J7.1, J10.1, Q2.8 (D), R66.1
/hsupply: C4.2, J7.2, Q1.1 (S), Q1.2 (S), Q1.3 (S), Q3.5 (D), U6.6 (VS)
B+H: C59.1, Q1.5 (D); also elsewhere on the board
GND: C2.2, C3.2, C6.2, C8.2, C9.2, C10.2, C59.2, H1.1, H2.1, H3.1, H4.1, Q3.1 (S), Q3.2 (S), Q3.3 (S), R4.2, R5.2, R10.2, R67.2, R72.2, U1.4 (GND), U6.4 (COM), U8.2 (GND), U8.4 (-), U9.3 (GND), U10.3 (GND); also elsewhere on the board
HOT_CURRENT: Q2.2 (DS), Q2.3 (S), Q2.4 (S), Q2.5 (S), Q2.6 (S), Q2.7 (S), R4.1, TP2.1; also elsewhere on the board
HOT_IN: R5.1, U1.3 (IN); also elsewhere on the board
HOT_VOLTAGE: R66.2, R67.1, TP1.1
H_CURRENT: U8.1; also elsewhere on the board
unnamed: C4.1, D1.1 (K), U6.8 (VB)
unnamed: Q1.4 (G), R64.1
unnamed: Q2.1 (G), R2.1
unnamed: Q3.4 (G), R65.1
unnamed: C13.2, Q8.2 (D), R23.1
unnamed: Q8.1 (G), U9.7 (OUT_A)
unnamed: C14.2, Q9.2 (D), R24.1
unnamed: Q9.1 (G), U9.5 (OUT_B)
unnamed: C15.2, Q10.2 (D), R25.1
unnamed: Q10.1 (G), U10.7 (OUT_A)
unnamed: C11.2, Q8.3 (S), Q9.3 (S), Q10.3 (S), Q11.3 (S), R23.2, R24.2, R25.2, R26.2, R28.2, R72.1, U8.3 (+)
unnamed: C16.2, Q11.2 (D), R26.1
unnamed: Q11.1 (G), U10.5 (OUT_B)
unnamed: R2.2, R10.1, U1.5 (OUT)
unnamed: R64.2, U6.7 (HO)
unnamed: R65.2, U6.5 (LO)
PIN_HI: U6.2 (HIN); also elsewhere on the board
PIN_LO: U6.3 (LIN); also elsewhere on the board
S0: U9.2 (IN_A); also elsewhere on the board
S1: U9.4 (IN_B); also elsewhere on the board
S2: U10.2 (IN_A); also elsewhere on the board
S3: U10.4 (IN_B); also elsewhere on the board
S_VOLTAGE: R27.2, R28.1; also elsewhere on the board
virtual_ground: U8.5 (REF); also elsewhere on the board

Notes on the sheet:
H.YOKE
R69 check size faster MOSFETs on class D output switch horizontal IRS2005 for something 250V rated switch S caps to have pulse rating big caps on 48V swap to wurth inductors add clamping output

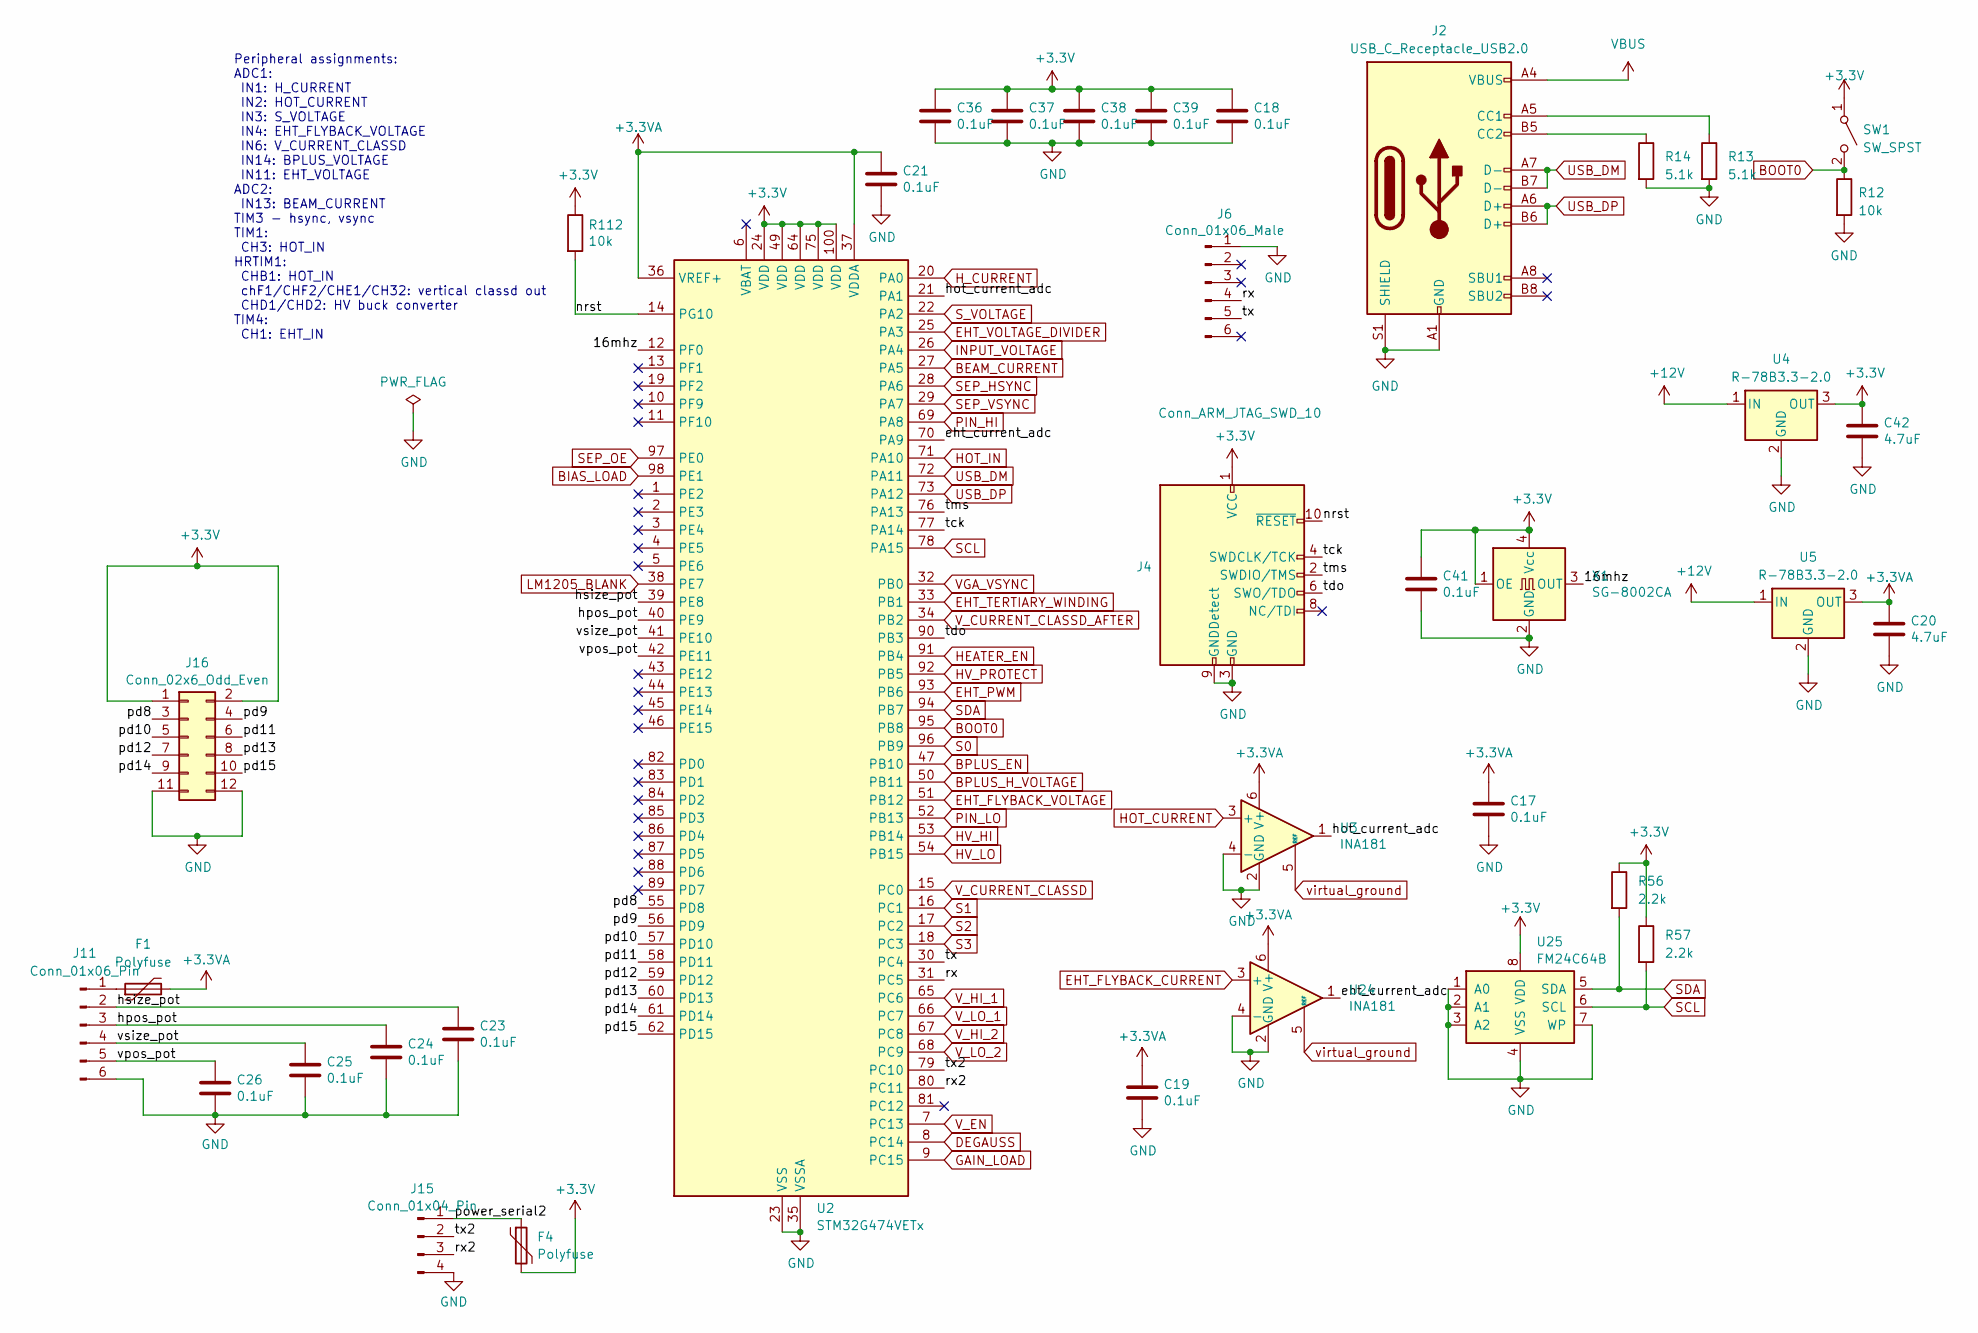
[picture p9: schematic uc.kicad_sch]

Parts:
C17, C18, C19, C21, C23, C24, C25, C26, C36, C37, C38, C39, C41: 0.1uF; C_0805_2012Metric_Pad1.18x1.45mm_HandSolder; Voltage 10V; Digikey 311-1140-1-ND
C20, C42: 4.7uF; C_1206_3216Metric; Voltage 10V; Digikey 1276-3177-1-ND
F1: Polyfuse; Fuse_0805_2012Metric; Digikey 507-1801-1-ND
F4: Polyfuse; Fuse_1206_3216Metric; Digikey 507-1801-1-ND
J2: USB_C_Receptacle_USB2.0; USB_C_Receptacle_XKB_U262-16XN-4BVC11; Digikey 2073-USB4105-GF-ACT-ND
J4: Conn_ARM_JTAG_SWD_10; PinHeader_2x05_P1.27mm_Vertical_SMD; Digikey SAM9438-ND
J6: Conn_01x06_Male; PinHeader_1x06_P2.54mm_Vertical; Digikey DNP
J11: Conn_01x06_Pin; JST_XH_B6B-XH-A_1x06_P2.50mm_Vertical; Digikey 455-B6B-XH-A-ND
J15: Conn_01x04_Pin; JST_XH_B4B-XH-A_1x04_P2.50mm_Vertical; Digikey 455-B4B-XH-A-ND
J16: Conn_02x6_Odd_Even; IDC-Header_2x06_P2.54mm_Vertical; Digikey 2057-BHR-12-VUA-ND
R12: 10k; R_0805_2012Metric; Digikey 311-10.0KCRCT-ND
R13, R14: 5.1k; R_0805_2012Metric; Digikey 311-5.10KCRCT-ND
R56, R57: 2.2k; R_0805_2012Metric; Digikey 311-2.20KCRCT-ND
R112: 10k; R_0805_2012Metric_Pad1.20x1.40mm_HandSolder; Digikey 311-10.0KCRCT-ND
SW1: SW_SPST; SW_DPDT_CK_JS202011JCQN; Digikey CKN10723CT-ND
U2: STM32G474VETx; LQFP-100_14x14mm_P0.5mm; Digikey 497-19476-ND
U3, U24: INA181; SOT-23-6; Digikey 296-47658-1-ND
U4, U5: R-78B3.3-2.0; Converter_DCDC_RECOM_R-78B-2.0_THT; Digikey 945-3040-ND
U25: FM24C64B; SOIC-8_3.9x4.9mm_P1.27mm; Digikey 448-FM24C64B-GTRCT-ND
X1: SG-8002CA; Oscillator_SMD_SeikoEpson_SG8002CA-4Pin_7.0x5.0mm; Digikey CTX270LVCT-ND

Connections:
+3.3V: C18.1, C36.1, C37.1, C38.1, C39.1, C41.1, C42.1, F4.2, J4.1 (VCC), J16.1, J16.2, R56.1, R57.1, R112.1, SW1.1 (A), U2.24 (VDD), U2.49 (VDD), U2.64 (VDD), U2.75 (VDD), U2.100 (VDD), U4.3 (OUT), U25.8 (VDD), X1.1 (OE), X1.4 (Vcc)
+3.3VA: C17.1, C19.1, C20.1, C21.1, F1.2, U2.36 (VREF+), U2.37 (VDDA), U3.6 (V+), U5.3 (OUT), U24.6 (V+); also elsewhere on the board
+12V: U4.1 (IN), U5.1 (IN); also elsewhere on the board
/uc/16mhz: U2.12 (PF0), X1.3 (OUT)
/uc/eht_current_adc: U2.70 (PA9), U24.1
/uc/hot_current_adc: U2.21 (PA1), U3.1
/uc/hpos_pot: C24.1, J11.3, U2.40 (PE9)
/uc/hsize_pot: C23.1, J11.2, U2.39 (PE8)
/uc/nrst: J4.10 (~RESET), R112.2, U2.14 (PG10)
/uc/pd8: J16.3, U2.55 (PD8)
/uc/pd9: J16.4, U2.56 (PD9)
/uc/pd10: J16.5, U2.57 (PD10)
/uc/pd11: J16.6, U2.58 (PD11)
/uc/pd12: J16.7, U2.59 (PD12)
/uc/pd13: J16.8, U2.60 (PD13)
/uc/pd14: J16.9, U2.61 (PD14)
/uc/pd15: J16.10, U2.62 (PD15)
/uc/power_serial2: F4.1, J15.1
/uc/rx: J6.4, U2.31 (PC5)
/uc/rx2: J15.3, U2.80 (PC11)
/uc/tck: J4.4 (SWDCLK/TCK), U2.77 (PA14)
/uc/tdo: J4.6 (SWO/TDO), U2.90 (PB3)
/uc/tms: J4.2 (SWDIO/TMS), U2.76 (PA13)
/uc/tx: J6.5, U2.30 (PC4)
/uc/tx2: J15.2, U2.79 (PC10)
/uc/vpos_pot: C26.1, J11.5, U2.42 (PE11)
/uc/vsize_pot: C25.1, J11.4, U2.41 (PE10)
BEAM_CURRENT: U2.27 (PA5); also elsewhere on the board
BIAS_LOAD: U2.98 (PE1); also elsewhere on the board
BOOT0: R12.1, SW1.2 (B), U2.95 (PB8)
BPLUS_EN: U2.47 (PB10); also elsewhere on the board
BPLUS_H_VOLTAGE: U2.50 (PB11); also elsewhere on the board
DEGAUSS: U2.8 (PC14); also elsewhere on the board
EHT_FLYBACK_CURRENT: U24.3 (+); also elsewhere on the board
EHT_FLYBACK_VOLTAGE: U2.51 (PB12); also elsewhere on the board
EHT_PWM: U2.93 (PB6); also elsewhere on the board
EHT_TERTIARY_WINDING: U2.33 (PB1); also elsewhere on the board
EHT_VOLTAGE_DIVIDER: U2.25 (PA3); also elsewhere on the board
GAIN_LOAD: U2.9 (PC15); also elsewhere on the board
GND: C17.2, C18.2, C19.2, C20.2, C21.2, C23.2, C24.2, C25.2, C26.2, C36.2, C37.2, C38.2, C39.2, C41.2, C42.2, J2.A1 (GND), J2.A12 (GND), J2.B1 (GND), J2.B12 (GND), J2.S1 (SHIELD), J4.3 (GND), J4.5 (GND), J4.9 (GNDDetect), J6.1, J11.6, J15.4, J16.11, J16.12, R12.2, R13.2, R14.2, U2.23 (VSS), U2.35 (VSSA), U2.48 (VSS), U2.63 (VSS), U2.74 (VSS), U2.99 (VSS), U3.2 (GND), U3.4 (-), U4.2 (GND), U5.2 (GND), U24.2 (GND), U24.4 (-), U25.1 (A0), U25.2 (A1), U25.3 (A2), U25.4 (VSS), U25.7 (WP), X1.2 (GND); also elsewhere on the board
HEATER_EN: U2.91 (PB4); also elsewhere on the board
HOT_CURRENT: U3.3 (+); also elsewhere on the board
HOT_IN: U2.71 (PA10); also elsewhere on the board
HV_HI: U2.53 (PB14); also elsewhere on the board
HV_LO: U2.54 (PB15); also elsewhere on the board
HV_PROTECT: U2.92 (PB5); also elsewhere on the board
H_CURRENT: U2.20 (PA0); also elsewhere on the board
INPUT_VOLTAGE: U2.26 (PA4); also elsewhere on the board
LM1205_BLANK: U2.38 (PE7); also elsewhere on the board
unnamed: J2.A5 (CC1), R13.1
unnamed: J2.B5 (CC2), R14.1
unnamed: F1.1, J11.1
PIN_HI: U2.69 (PA8); also elsewhere on the board
PIN_LO: U2.52 (PB13); also elsewhere on the board
S0: U2.96 (PB9); also elsewhere on the board
S1: U2.16 (PC1); also elsewhere on the board
S2: U2.17 (PC2); also elsewhere on the board
S3: U2.18 (PC3); also elsewhere on the board
SCL: R57.2, U2.78 (PA15), U25.6 (SCL); also elsewhere on the board
SDA: R56.2, U2.94 (PB7), U25.5 (SDA); also elsewhere on the board
SEP_HSYNC: U2.28 (PA6); also elsewhere on the board
SEP_OE: U2.97 (PE0); also elsewhere on the board
SEP_VSYNC: U2.29 (PA7); also elsewhere on the board
S_VOLTAGE: U2.22 (PA2); also elsewhere on the board
USB_DM: J2.A7 (D-), J2.B7 (D-), U2.72 (PA11)
USB_DP: J2.A6 (D+), J2.B6 (D+), U2.73 (PA12)
VBUS: J2.A4 (VBUS), J2.A9 (VBUS), J2.B4 (VBUS), J2.B9 (VBUS)
VGA_VSYNC: U2.32 (PB0); also elsewhere on the board
V_CURRENT_CLASSD: U2.15 (PC0); also elsewhere on the board
V_CURRENT_CLASSD_AFTER: U2.34 (PB2); also elsewhere on the board
V_EN: U2.7 (PC13)
V_HI_1: U2.65 (PC6); also elsewhere on the board
V_HI_2: U2.67 (PC8); also elsewhere on the board
V_LO_1: U2.66 (PC7); also elsewhere on the board
V_LO_2: U2.68 (PC9); also elsewhere on the board
virtual_ground: U3.5 (REF), U24.5 (REF); also elsewhere on the board

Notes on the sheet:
Peripheral assignments: ADC1: IN1: H_CURRENT IN2: HOT_CURRENT IN3: S_VOLTAGE IN4: EHT_FLYBACK_VOLTAGE IN6: V_CURRENT_CLASSD IN14: BPLUS_VOLTAGE IN11: EHT_VOLTAGE ADC2: IN13: BEAM_CURRENT TIM3 - hsync, vsync TIM1: CH3: HOT_IN HRTIM1: CHB1: HOT_IN chF1/CHF2/CHE1/CH32: vertical classd out CHD1/CHD2: H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

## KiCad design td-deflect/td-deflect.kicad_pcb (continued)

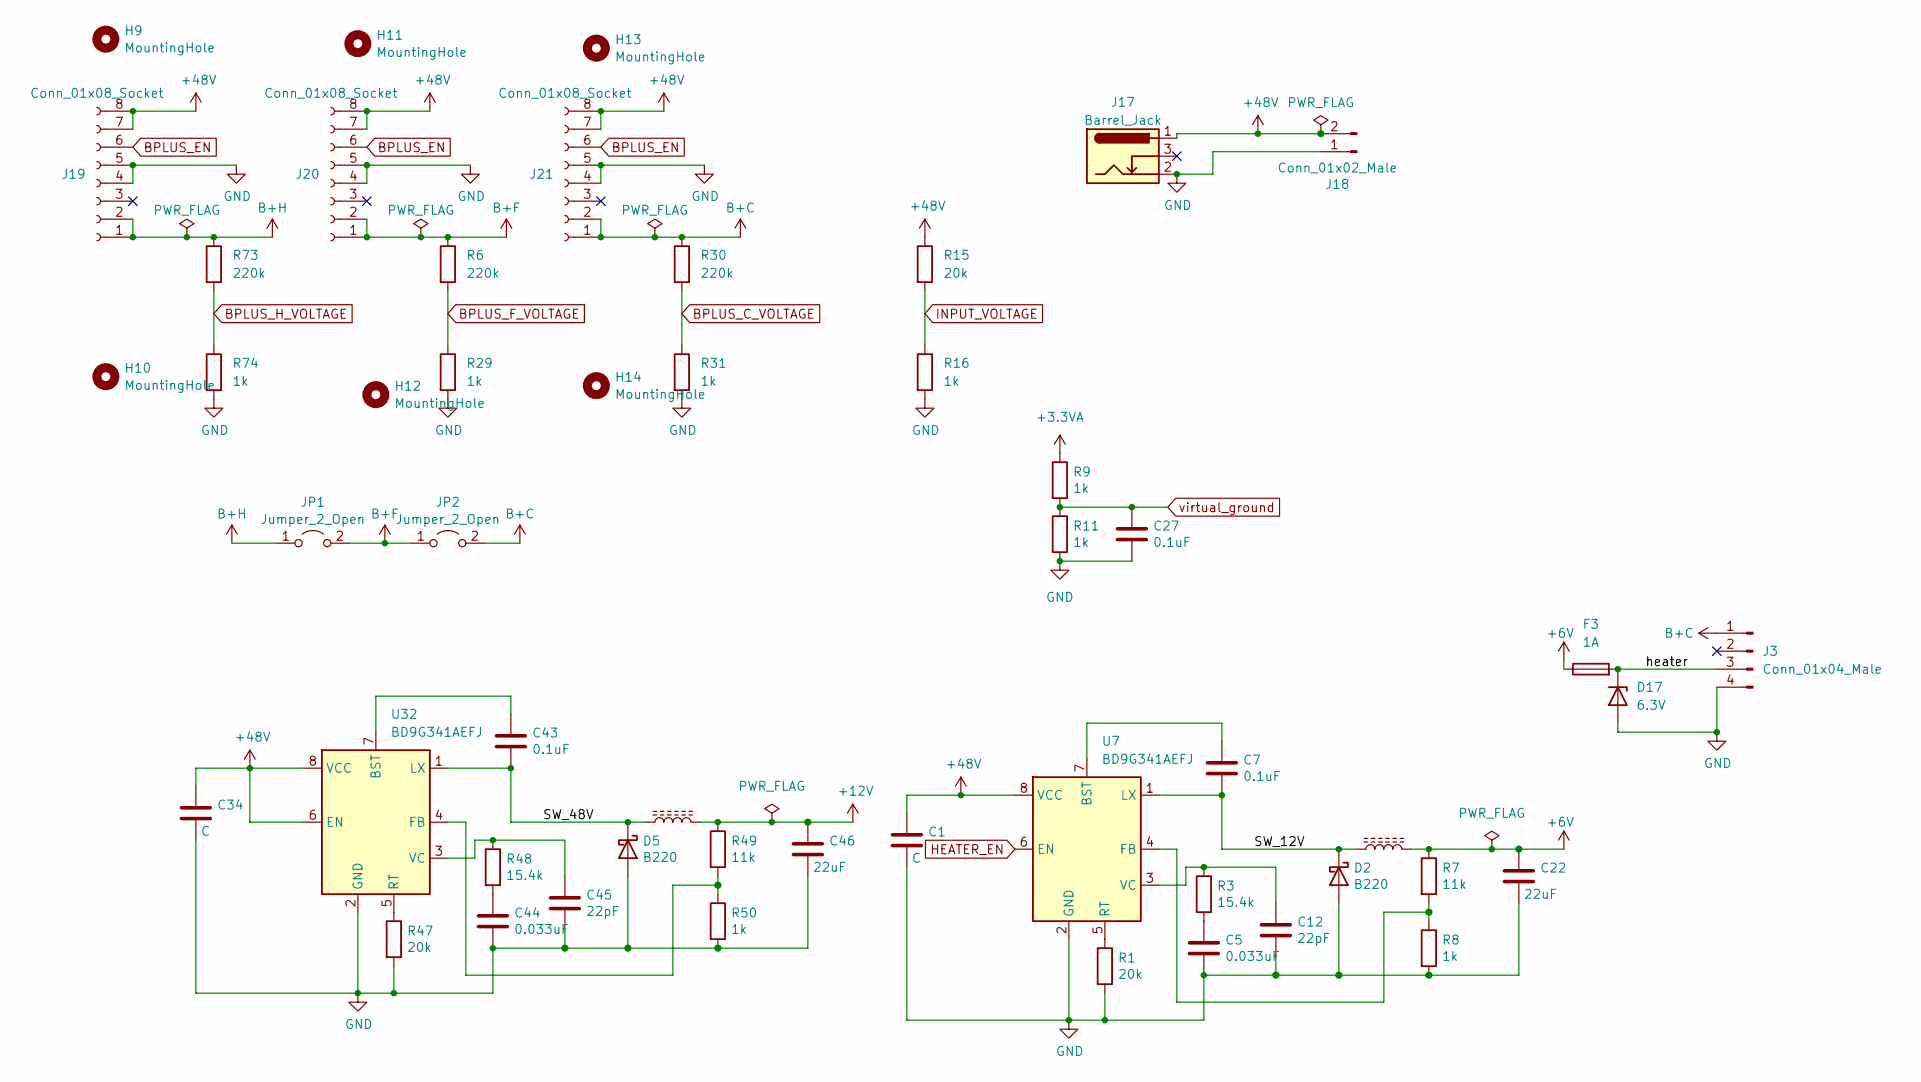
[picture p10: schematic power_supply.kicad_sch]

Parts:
C1, C34: C; C_1210_3225Metric; Voltage 50V; Digikey 587-1818-1-ND
C5, C44: 0.033uF; C_0805_2012Metric; Voltage 10V; Digikey 311-1374-1-ND
C7, C27, C43: 0.1uF; C_0805_2012Metric; Voltage 25V; Digikey 1276-1099-1-ND
C12, C45: 22pF; C_0805_2012Metric; Digikey 1276-2605-1-ND
C22, C46: 22uF; C_0805_2012Metric; Voltage 16V; Digikey 490-9956-1-ND
D2, D5: B220; D_SMB; Digikey B220A-FDICT-ND
D17: 6.3V; D_SMA; Digikey SMAJ6.5A-FDICT-ND
F3: 1A; Fuse_Schurter_UMT250; Digikey 486-3436-ND
H9, H10, H11, H12, H13, H14: MountingHole; MountingHole_3.2mm_M3; Digikey DNP
J3: Conn_01x04_Male; JST_XH_B4B-XH-A_1x04_P2.50mm_Vertical; Digikey 455-B4B-XH-A-ND
J17: Barrel_Jack; BarrelJack_Wuerth_6941xx301002; Digikey 732-5930-ND
J18: Conn_01x02_Male; PhoenixContact_MSTBVA_2,5_2-G_1x02_P5.00mm_Vertical; Digikey 277-1150-ND
J19, J20, J21: Conn_01x08_Socket; PinSocket_1x08_P2.54mm_Vertical; Digikey S7041-ND
JP1, JP2: Jumper_2_Open; PinHeader_1x02_P2.54mm_Vertical; Digikey DNP
L1, L5: 47uH; L_Bourns_SRR1260; Digikey SRF1260-470MCT-ND
R1, R47: 20k; R_0805_2012Metric; Digikey 311-20.0KCRCT-ND
R3, R48: 15.4k; R_0805_2012Metric; Digikey 311-15.4KCRCT-ND
R6, R30, R73: 220k; R_0805_2012Metric_Pad1.20x1.40mm_HandSolder; Digikey 311-220KCRCT-ND
R7, R49: 11k; R_0805_2012Metric; Digikey 311-11.0KCRCT-ND
R8, R9, R11, R50: 1k; R_0805_2012Metric; Digikey 311-1.00KCRCT-ND
R15: 20k; R_0805_2012Metric_Pad1.20x1.40mm_HandSolder; Digikey 311-20.0KCRCT-ND
R16, R29, R31, R74: 1k; R_0805_2012Metric_Pad1.20x1.40mm_HandSolder; Digikey 311-1.00KCRCT-ND
U7, U32: BD9G341AEFJ; SOIC-8-1EP_3.9x4.9mm_P1.27mm_EP2.41x3.3mm_ThermalVias; Digikey BD9G341AEFJ-E2CT-ND

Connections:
+3.3VA: R9.1; also elsewhere on the board
+6V: C22.1, F3.1, L1.2, R7.1
+12V: C46.1, L5.2, R49.1; also elsewhere on the board
+48V: C1.1, C34.1, J17.1, J18.2, J19.7, J19.8, J20.7, J20.8, J21.7, J21.8, R15.1, U7.8 (VCC), U32.6 (EN), U32.8 (VCC); also elsewhere on the board
/power_supply/SW_12V: C7.2, D2.1 (K), L1.1, U7.1 (LX)
/power_supply/SW_48V: C43.2, D5.1 (K), L5.1, U32.1 (LX)
/power_supply/heater: D17.1 (K), F3.2, J3.3
B+C: J3.1, J21.1, J21.2, JP2.2 (B), R30.1
B+F: J20.1, J20.2, JP1.2 (B), JP2.1 (A), R6.1; also elsewhere on the board
B+H: J19.1, J19.2, JP1.1 (A), R73.1; also elsewhere on the board
BPLUS_C_VOLTAGE: R30.2, R31.1
BPLUS_EN: J19.6, J20.6, J21.6; also elsewhere on the board
BPLUS_F_VOLTAGE: R6.2, R29.1
BPLUS_H_VOLTAGE: R73.2, R74.1; also elsewhere on the board
GND: C1.2, C5.2, C12.2, C22.2, C27.2, C34.2, C44.2, C45.2, C46.2, D2.2 (A), D5.2 (A), D17.2 (A), J3.4, J17.2, J18.1, J19.4, J19.5, J20.4, J20.5, J21.4, J21.5, R1.2, R8.2, R11.2, R16.2, R29.2, R31.2, R47.2, R50.2, R74.2, U7.2 (GND), U7.9 (GND), U32.2 (GND), U32.9 (GND); also elsewhere on the board
HEATER_EN: U7.6 (EN); also elsewhere on the board
INPUT_VOLTAGE: R15.2, R16.1; also elsewhere on the board
unnamed: C5.1, R3.2
unnamed: C44.1, R48.2
unnamed: C7.1, U7.7 (BST)
unnamed: R7.2, R8.1, U7.4 (FB)
unnamed: R1.1, U7.5 (RT)
unnamed: C12.1, R3.1, U7.3 (VC)
unnamed: C43.1, U32.7 (BST)
unnamed: R49.2, R50.1, U32.4 (FB)
unnamed: R47.1, U32.5 (RT)
unnamed: C45.1, R48.1, U32.3 (VC)
virtual_ground: C27.1, R9.2, R11.1; also elsewhere on the board

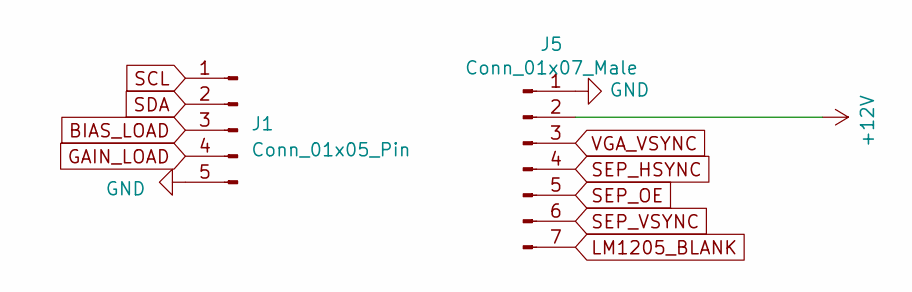
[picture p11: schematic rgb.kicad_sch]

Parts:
J1: Conn_01x05_Pin; JST_XH_B5B-XH-A_1x05_P2.50mm_Vertical; Digikey 455-B5B-XH-A-ND
J5: Conn_01x07_Male; JST_XH_B7B-XH-A_1x07_P2.50mm_Vertical; Digikey 1175-51025-07-0100-01-ND

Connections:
+12V: J5.2; also elsewhere on the board
BIAS_LOAD: J1.3; also elsewhere on the board
GAIN_LOAD: J1.4; also elsewhere on the board
GND: J1.5, J5.1; also elsewhere on the board
LM1205_BLANK: J5.7; also elsewhere on the board
SCL: J1.1; also elsewhere on the board
SDA: J1.2; also elsewhere on the board
SEP_HSYNC: J5.4; also elsewhere on the board
SEP_OE: J5.5; also elsewhere on the board
SEP_VSYNC: J5.6; also elsewhere on the board
VGA_VSYNC: J5.3; also elsewhere on the board

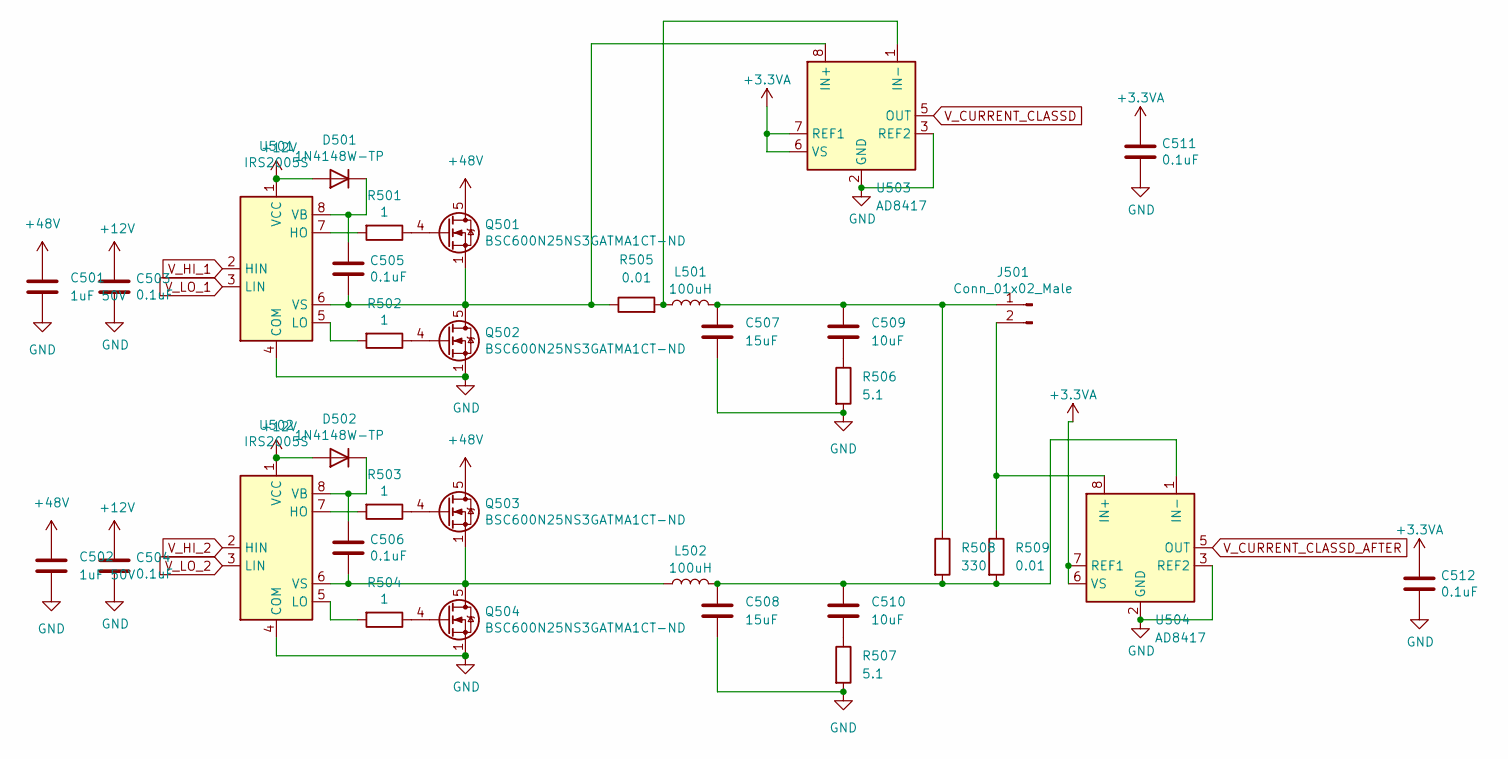
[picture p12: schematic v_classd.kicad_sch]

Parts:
C501, C502: 1uF 50V; C_0805_2012Metric_Pad1.18x1.45mm_HandSolder; Digikey 13-CC0805KFX7R9BB105CT-ND
C503, C504, C505, C506, C511, C512: 0.1uF; C_0805_2012Metric_Pad1.18x1.45mm_HandSolder; Digikey 311-1140-1-ND
C507, C508: 15uF; C_Elec_6.3x7.7; Digikey 565-HHXD500ARA150MF80GCT-ND
C509, C510: 10uF; C_Elec_6.3x5.8; Digikey 565-4781-1-ND
D501, D502: 1N4148W-TP; D_SOD-123; Digikey 1N4148WTPMSCT-ND
J501: Conn_01x02_Male; sony_monitor_2p; Digikey DNP
L501, L502: 100uH; L_Bourns_SRR1260; Digikey 4044-CSAB1260A-101MCT-ND
Q501, Q502, Q503, Q504: BSC600N25NS3GATMA1CT-ND; TDSON-8-1; Digikey BSC600N25NS3GATMA1CT-ND
R501, R502, R503, R504: 1; R_0805_2012Metric_Pad1.20x1.40mm_HandSolder; Digikey 311-1.00CRCT-ND
R505, R509: 0.01; R_0805_2012Metric_Pad1.20x1.40mm_HandSolder; Digikey 311-0.01NUCT-ND
R506, R507: 5.1; R_0805_2012Metric_Pad1.20x1.40mm_HandSolder; Digikey 311-5.1ARCT-ND
R508: 330; R_0805_2012Metric_Pad1.20x1.40mm_HandSolder; Digikey 13-RC0805FR-13330RLCT-ND
U501, U502: IRS2005S; SOIC-8_3.9x4.9mm_P1.27mm; Digikey IRS2005STRPBFCT-ND
U503, U504: AD8417; SOIC-8_3.9x4.9mm_P1.27mm; Digikey 505-AD8417WBRZ-ND

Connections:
+3.3VA: C511.1, C512.1, U503.6 (VS), U503.7 (REF1), U504.6 (VS), U504.7 (REF1); also elsewhere on the board
+12V: C503.1, C504.1, D501.2 (A), D502.2 (A), U501.1 (VCC), U502.1 (VCC); also elsewhere on the board
+48V: C501.1, C502.1, Q501.5 (D), Q503.5 (D); also elsewhere on the board
GND: C501.2, C502.2, C503.2, C504.2, C507.2, C508.2, C511.2, C512.2, Q502.1 (S), Q502.2 (S), Q502.3 (S), Q504.1 (S), Q504.2 (S), Q504.3 (S), R506.2, R507.2, U501.4 (COM), U502.4 (COM), U503.2 (GND), U503.3 (REF2), U504.2 (GND), U504.3 (REF2); also elsewhere on the board
unnamed: C509.2, R506.1
unnamed: C510.2, R507.1
unnamed: C505.1, D501.1 (K), U501.8 (VB)
unnamed: C506.1, D502.1 (K), U502.8 (VB)
unnamed: C507.1, C509.1, J501.1, L501.2, R508.1
unnamed: J501.2, R509.1, U504.8 (IN+)
unnamed: Q501.4 (G), R501.1
unnamed: C505.2, Q501.1 (S), Q501.2 (S), Q501.3 (S), Q502.5 (D), R505.1, U501.6 (VS), U503.8 (IN+)
unnamed: Q502.4 (G), R502.1
unnamed: Q503.4 (G), R503.1
unnamed: C506.2, L502.1, Q503.1 (S), Q503.2 (S), Q503.3 (S), Q504.5 (D), U502.6 (VS)
unnamed: Q504.4 (G), R504.1
unnamed: R501.2, U501.7 (HO)
unnamed: R502.2, U501.5 (LO)
unnamed: R503.2, U502.7 (HO)
unnamed: R504.2, U502.5 (LO)
unnamed: L501.1, R505.2, U503.1 (IN-)
unnamed: C508.1, C510.1, L502.2, R508.2, R509.2, U504.1 (IN-)
V_CURRENT_CLASSD: U503.5 (OUT); also elsewhere on the board
V_CURRENT_CLASSD_AFTER: U504.5 (OUT); also elsewhere on the board
V_HI_1: U501.2 (HIN); also elsewhere on the board
V_HI_2: U502.2 (HIN); also elsewhere on the board
V_LO_1: U501.3 (LIN); also elsewhere on the board
V_LO_2: U502.3 (LIN); also elsewhere on the board

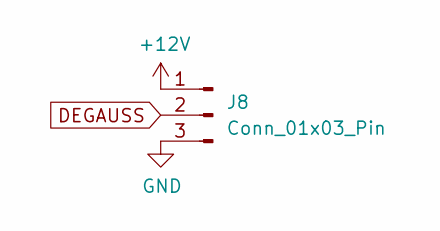
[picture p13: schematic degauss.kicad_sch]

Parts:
J8: Conn_01x03_Pin; JST_XH_B3B-XH-A_1x03_P2.50mm_Vertical; Digikey 455-2248-ND

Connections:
+12V: J8.1; also elsewhere on the board
DEGAUSS: J8.2; also elsewhere on the board
GND: J8.3; also elsewhere on the board

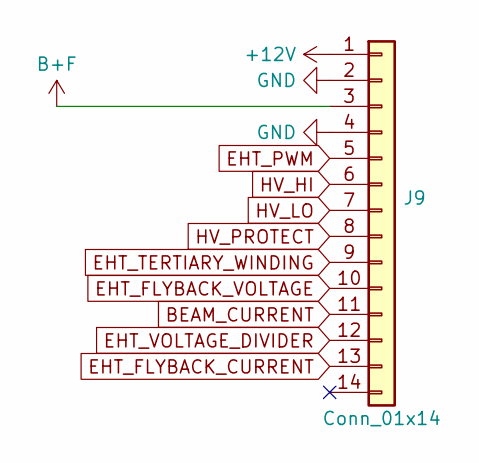
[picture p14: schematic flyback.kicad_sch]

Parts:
J9: Conn_01x14; JST_XH_B14B-XH-A_1x14_P2.50mm_Vertical; Digikey 455-B14B-XH-A-ND

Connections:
+12V: J9.1; also elsewhere on the board
B+F: J9.3; also elsewhere on the board
BEAM_CURRENT: J9.11; also elsewhere on the board
EHT_FLYBACK_CURRENT: J9.13; also elsewhere on the board
EHT_FLYBACK_VOLTAGE: J9.10; also elsewhere on the board
EHT_PWM: J9.5; also elsewhere on the board
EHT_TERTIARY_WINDING: J9.9; also elsewhere on the board
EHT_VOLTAGE_DIVIDER: J9.12; also elsewhere on the board
GND: J9.2, J9.4; also elsewhere on the board
HV_HI: J9.6; also elsewhere on the board
HV_LO: J9.7; also elsewhere on the board
HV_PROTECT: J9.8; also elsewhere on the board


Board: 4 copper layers, 174.0 x 104.0 mm, 175 parts (0 on the bottom side), 133 nets.

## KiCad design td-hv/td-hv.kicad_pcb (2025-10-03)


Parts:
C9: 1uF; C_0805_2012Metric; Digikey 311-1365-1-ND
F1: 400mA; Fuse_Schurter_UMZ250; Digikey 486-4326-ND
H1, H2, H3, H4: MountingHole_Pad; MountingHole_3.2mm_M3_Pad_Via; Digikey DNP
J1: Conn_01x14; JST_XH_B14B-XH-A_1x14_P2.50mm_Vertical; Digikey 455-B14B-XH-A-ND
U7: AP2205; SOT-23-5; Digikey 31-AP2205-33W5-7CT-ND

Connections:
+3.3V: C9.1, U7.5 (VOUT); also elsewhere on the board
+12V: J1.1, U7.1 (VIN), U7.3 (EN); also elsewhere on the board
BEAM_CURRENT: J1.11; also elsewhere on the board
EHT_FLYBACK_CURRENT: J1.13; also elsewhere on the board
EHT_FLYBACK_VOLTAGE: J1.10; also elsewhere on the board
EHT_PWM: J1.5; also elsewhere on the board
EHT_TERTIARY_WINDING: J1.9; also elsewhere on the board
EHT_VOLTAGE_DIVIDER: J1.12; also elsewhere on the board
GND: C9.2, H1.1, H2.1, H3.1, H4.1, J1.2, J1.4, U7.2 (GND); also elsewhere on the board
HT: F1.1; also elsewhere on the board
HV_HI: J1.6; also elsewhere on the board
HV_LO: J1.7; also elsewhere on the board
HV_PROTECT: J1.8; also elsewhere on the board
unnamed: F1.2, J1.3


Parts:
C1, C3, C4, C7, C19: 0.1uF; C_0805_2012Metric; Digikey 1276-1099-1-ND
C2: 15uF 250V; CP_Elec_10x10.5; Digikey 493-6738-1-ND
C5: 47pF 2000V NP0; C_1812_4532Metric; Digikey 478-3005-1-ND
C6: 0.01uF; C_0805_2012Metric; Digikey 311-1136-1-ND
C8: 0.1uF 250V; C_1206_3216Metric; Digikey 445-8899-1-ND
C24: 4700pF 2000V; C_Rect_L18.0mm_W5.0mm_P15.00mm_FKS3_FKP3; Voltage 2000V; Digikey 495-3227-ND
D1: RED; LED_0805_2012Metric; Digikey 350-2039-1-ND
D2: DNP; D_SMA; Digikey ES1G-FDICT-ND
D3, D4: BAT54A; SOT-23; Digikey 1655-BAT54ACT-ND
JP1: Jumper_2_Open; PinHeader_1x02_P2.54mm_Vertical
L1: 053X0528-001; Digikey DNP
Q1, Q2: BSZ42DN25NS3GATMA1; TDSON-8-1; Digikey BSZ42DN25NS3GATMA1CT-ND
Q12: G3R450MT17J; TO-263-7_TabPin8_GeneSiC; Digikey 1242-G3R450MT17J-ND
R1, R2, R8, R9, R42, R106: 1k; R_0805_2012Metric; Digikey 311-1.00KCRCT-ND
R3, R4, R35: 1; R_0805_2012Metric; Digikey 311-1.00CRCT-ND
R5, R10, R11, R33, R34: 10k; R_0805_2012Metric; Digikey 311-1.00KCRCT-ND
R6: 3k; R_2512_6332Metric; Digikey 13-RC2512FK-073KLCT-ND
R7: 47k; R_0805_2012Metric; Digikey 311-47.0KCRCT-ND
R12, R15: 1k; R_0805_2012Metric
R13: 10k; R_0805_2012Metric
R14, R16, R17, R19: 1k; R_0805_2012Metric; not fitted
R36: 0.01; R_0805_2012Metric; Digikey 311-0.01NUCT-ND
R41: 1M 3000V; R_2512_6332Metric; Digikey CHV2512-FX-1004ELFCT-ND
R105: 22k; R_0805_2012Metric; Digikey 311-22.0KCRCT-ND
RV1: 10k; Potentiometer_Bourns_3314G_Vertical; Digikey 563-ST4ETB103CT-ND
TP4, TP6, TP7, TP8, TP9, TP10: TestPoint; TestPoint_Keystone_5019_Miniature; Digikey 36-5019CT-ND
U1: 74HC00; SOIC-14_3.9x8.7mm_P1.27mm; Digikey 1727-2773-1-ND
U2: LM2903; SOIC-8_3.9x4.9mm_P1.27mm; Digikey LM2903QS-13DICT-ND
U4: 2ED2101S06FXUMA1; SOIC-8_3.9x4.9mm_P1.27mm; Digikey 448-2ED2101S06FXUMA1CT-ND
U13: MCP1416; SOT-23-5; Digikey MCP1416T-E/OTCT-ND

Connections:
+3.3V: R1.1, R2.1, R9.1, U1.14 (VCC); also elsewhere on the board
+12V: C1.1, C19.1, D2.2 (A), R5.1, U2.8 (V+), U4.1 (VCC), U13.2 (Vdd); also elsewhere on the board
/flyback/eht out: C24.1, L1.1, Q12.8 (D), R6.1, R41.1
/flyback/snub: C5.1, R6.2
BEAM_CURRENT: C6.1, L1.8, R8.1, TP6.1; also elsewhere on the board
EHT_FLYBACK_CURRENT: Q12.2 (DS), Q12.3 (S), Q12.4 (S), Q12.5 (S), Q12.6 (S), Q12.7 (S), R36.1; also elsewhere on the board
EHT_FLYBACK_VOLTAGE: R41.2, R42.1, TP4.1; also elsewhere on the board
EHT_PWM: R33.1, U1.2; also elsewhere on the board
EHT_TERTIARY_WINDING: R105.2, R106.1; also elsewhere on the board
EHT_VOLTAGE_DIVIDER: L1.7, R7.1, TP7.1; also elsewhere on the board
GND: C1.2, C2.2, C4.2, C6.2, C7.2, C8.2, C19.2, C24.2, L1.3, Q2.1 (S), Q2.2 (S), Q2.3 (S), R7.2, R8.2, R10.2, R11.2, R12.2, R17.1, R19.2, R33.2, R34.2, R36.2, R42.2, R106.2, RV1.1, U1.7 (GND), U1.9, U1.10, U1.12, U1.13, U2.4 (V-), U4.4 (COM), U13.4 (GND); also elsewhere on the board
HT: C2.1, C8.1, JP1.1 (A), Q1.5 (D); also elsewhere on the board
HV_HI: R10.1, U4.2 (HIN); also elsewhere on the board
HV_LO: R11.1, U4.3 (LIN); also elsewhere on the board
HV_PROTECT: D1.1 (K), R9.2, U2.7; also elsewhere on the board
unnamed: C7.1, D4.2, R105.1, TP9.1
unnamed: D1.2 (A), R1.2
unnamed: C3.1, D2.1 (K), U4.8 (VB)
unnamed: D3.3, R13.1, R14.1, R19.1
unnamed: D4.3, R15.2, R16.2, R17.2, TP8.1
unnamed: C3.2, C5.2, JP1.2 (B), L1.2, Q1.1 (S), Q1.2 (S), Q1.3 (S), Q2.5 (D), U4.6 (VS)
unnamed: L1.4, R15.1
unnamed: L1.5, R13.2
unnamed: L1.6, R14.2, R16.1
unnamed: Q1.4 (G), R3.1
unnamed: Q2.4 (G), R4.1
unnamed: Q12.1 (G), R35.1
unnamed: R2.2, U1.1, U2.1
unnamed: R5.2, RV1.3
unnamed: U1.3, U1.4, U1.5
unnamed: RV1.2, U2.3 (+), U2.5 (+)
unnamed: C4.1, D3.2, R12.1, TP10.1, U2.2 (-), U2.6 (-)
unnamed: R3.2, U4.7 (HO)
unnamed: R4.2, U4.5 (LO)
unnamed: U1.6, U13.3 (IN)
unnamed: R34.1, R35.2, U13.5 (OUT)

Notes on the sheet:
~24V
~12V
todo: 24V diode too low voltage 12V feedback too high voltage switch polarity of feedback
1-2: 4.897mH 3-4: 220.9uH 3-5: 64.2uH 3-6: 131.0uH 4-5: 51.95uH 5-6: 356.4uH 5-7: nc 5-10: nc 7-8: nc 7-9: 3.75uH 7-10: 115.31uH 9-10: 80.98uH
todo: fix this symbol todo: figure out dots
HV PROTECT


Board: 2 copper layers, 90.0 x 71.0 mm, 64 parts (0 on the bottom side), 37 nets.

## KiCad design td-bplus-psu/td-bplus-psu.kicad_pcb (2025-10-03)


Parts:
C1: 0.1uF; C_0805_2012Metric; Digikey 399-C0805C104M5RAC7800CT-ND
C2: 1uF; C_2220_5750Metric_Pad1.97x5.40mm_HandSolder; Voltage 250V; Digikey 490-13318-1-ND
C18: C_Polarized; CP_Elec_6.3x5.9; Voltage 63V; Digikey P15466CT-ND
C20: 0.01uF; C_0805_2012Metric_Pad1.18x1.45mm_HandSolder; Voltage 10V; Digikey 1276-2434-1-ND
C21: 100pF; C_0805_2012Metric_Pad1.18x1.45mm_HandSolder; Voltage 10V; Digikey 1276-2569-1-ND
C22: 1uF; C_0805_2012Metric; Voltage 10V; Digikey 587-2229-1-ND
C23: 4.7uF; C_0805_2012Metric_Pad1.18x1.45mm_HandSolder; Voltage 10V; Digikey 1276-3177-1-ND
C25: 8.2uF; CP_Radial_D10.0mm_P5.00mm; Voltage 250V; Digikey 399-14135-ND
C26: 0.1uF; C_1206_3216Metric_Pad1.33x1.80mm_HandSolder; Voltage 250V; Digikey 311-4585-1-ND
D3: WNSC2D04650DJ; TO-252-2_TabPin1; Digikey 1740-WNSC2D04650DJCT-ND
H1, H2: MountingHole; MountingHole_2.7mm_M2.5
J1: Conn_01x08_Pin; PinHeader_1x08_P2.54mm_Horizontal
L3: 10uH; L_Wuerth_HCI-1040; Digikey 732-4179-1-ND
Q13: TDSON-8-1
R29: 1M; R_0805_2012Metric_Pad1.20x1.40mm_HandSolder; Digikey 311-1.00MCRCT-ND
R30: 100k; R_0805_2012Metric_Pad1.20x1.40mm_HandSolder; Digikey 311-100KCRCT-ND
R31, R32: 49.9k; R_0805_2012Metric_Pad1.20x1.40mm_HandSolder; Digikey 311-49.9KCRCT-ND
R37: 0.01; R_0805_2012Metric_Pad1.20x1.40mm_HandSolder; Digikey 311-0.01NUCT-ND
R39: 70K; R_1206_3216Metric_Pad1.30x1.75mm_HandSolder; Digikey 311-68.0KFRCT-ND
R40: 470; R_0805_2012Metric_Pad1.20x1.40mm_HandSolder; Digikey 311-470CRCT-ND
RV1: 5k; Potentiometer_Bourns_3314S_Horizontal; Digikey 3314S-1-502ECT-ND
U14: LT3758AEMSE; MSOP-10-1EP_3x3mm_P0.5mm_EP1.68x1.88mm; Digikey LT3758AEMSE#TRPBFCT-ND

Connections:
+48V: C1.1, C18.1, J1.7, J1.8, L3.1, R29.1, U14.10 (VIN)
/SW: D3.2 (A), L3.2, Q13.5 (D)
BPLUS_EN: J1.6, R29.2, R30.1, U14.9 (~SHDN~/UVLO)
GND: C1.2, C2.2, C18.2, C20.2, C21.2, C22.2, C23.2, C25.2, C26.2, J1.4, J1.5, R30.2, R31.2, R37.2, R40.2, U14.5 (SYNC), U14.11 (GND)
HT: C2.1, C25.1, C26.1, D3.1 (K), J1.1, J1.2, R39.1
unnamed: C20.1, R32.2
unnamed: Q13.4 (G), U14.7 (GATE)
unnamed: R39.2, RV1.3
unnamed: R40.1, RV1.1
unnamed: RV1.2, U14.2 (FBX)
unnamed: C23.1, U14.8 (INTVCC)
unnamed: R31.1, U14.4 (RT)
unnamed: Q13.1 (S), Q13.2 (S), Q13.3 (S), R37.1, U14.6 (SENSE)
unnamed: C22.1, U14.3 (SS)
unnamed: C21.1, R32.1, U14.1 (VC)

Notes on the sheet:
todo: switch capacitors for surface mount


Board: 2 copper layers, 40.0 x 40.0 mm, 24 parts (0 on the bottom side), 15 nets.

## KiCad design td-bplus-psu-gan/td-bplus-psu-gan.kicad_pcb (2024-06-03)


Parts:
C1: 0.1uF; C_0805_2012Metric; Digikey 399-C0805C104M5RAC7800CT-ND
C2: C_Polarized; CP_Elec_6.3x5.9; Voltage 63V; Digikey P15466CT-ND
C3: 0.01uF; C_0805_2012Metric_Pad1.18x1.45mm_HandSolder; Voltage 10V; Digikey 1276-2434-1-ND
C4: 100pF; C_0805_2012Metric_Pad1.18x1.45mm_HandSolder; Voltage 10V; Digikey 1276-2569-1-ND
C5: 1uF; C_0805_2012Metric; Voltage 10V; Digikey 587-2229-1-ND
C6: 4.7uF; C_0805_2012Metric_Pad1.18x1.45mm_HandSolder; Voltage 10V; Digikey 1276-3177-1-ND
C7: 10uF; CP_Radial_D10.0mm_P5.00mm; Voltage 300V; Digikey 732-8889-1-ND
C8: 0.1uF; C_1206_3216Metric_Pad1.33x1.80mm_HandSolder; Voltage 250V; Digikey 311-4585-1-ND
C9, C10: 1uF; C_1812_4532Metric; Digikey 4713-CHV1812N250105KXTCT-ND
D1: WNSC2D04650DJ; TO-252-2_TabPin1; Digikey 1740-WNSC2D04650DJCT-ND
FB1: FerriteBead_Small; R_0603_1608Metric; Digikey 1712-BMC1JY0240ANCT-ND
H1, H2: MountingHole; MountingHole_2.7mm_M2.5
J1: Conn_01x08_Pin; PinHeader_1x08_P2.54mm_Horizontal; Digikey 609-3321-ND
L1: 10uH; L_Wuerth_HCI-1040; Digikey PCD2467CT-ND
Q1: Trasphorm_Power_DFN-8L_5x6; Digikey 1707-TP65H480G4JSGB-TRCT-ND
R1: 1M; R_0805_2012Metric_Pad1.20x1.40mm_HandSolder; Digikey 311-1.00MCRCT-ND
R2: 100k; R_0805_2012Metric_Pad1.20x1.40mm_HandSolder; Digikey 311-100KCRCT-ND
R3, R4: 49.9k; R_0805_2012Metric_Pad1.20x1.40mm_HandSolder; Digikey 311-49.9KCRCT-ND
R5: 0.01; R_0805_2012Metric_Pad1.20x1.40mm_HandSolder; Digikey 311-0.01NUCT-ND
R6: 70K; R_1206_3216Metric_Pad1.30x1.75mm_HandSolder; Digikey 311-68.0KFRCT-ND
R7: 470; R_0805_2012Metric_Pad1.20x1.40mm_HandSolder; Digikey 311-470CRCT-ND
R8: 75; R_0805_2012Metric; Digikey 311-75.0CRCT-ND
RV1: 5k; Potentiometer_Bourns_3314S_Horizontal; Digikey 3314S-1-502ECT-ND
U1: LT3758AEMSE; MSOP-10-1EP_3x3mm_P0.5mm_EP1.68x1.88mm; Digikey LT3758AEMSE#TRPBFCT-ND

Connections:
+48V: C1.1, C2.1, J1.7, J1.8, L1.1, R1.1, U1.10 (VIN)
/SW: D1.2 (A), L1.2, Q1.5 (D), Q1.6 (D), Q1.7 (D), Q1.8 (D)
BPLUS_EN: J1.6, R1.2, R2.1, U1.9 (~SHDN~/UVLO)
GND: C1.2, C2.2, C3.2, C4.2, C5.2, C6.2, C7.2, C8.2, C9.2, C10.2, J1.4, J1.5, R2.2, R3.2, R5.2, R7.2, U1.5 (SYNC), U1.11 (GND)
HT: C7.1, C8.1, C9.1, C10.1, D1.1 (K), J1.1, J1.2, R6.1
unnamed: C3.1, R4.2
unnamed: FB1.2, R8.2
unnamed: FB1.1, Q1.4 (G)
unnamed: Q1.0 (S), Q1.3 (KS), R5.1, U1.6 (SENSE)
unnamed: R6.2, RV1.3
unnamed: R7.1, RV1.1
unnamed: RV1.2, U1.2 (FBX)
unnamed: R8.1, U1.7 (GATE)
unnamed: C6.1, U1.8 (INTVCC)
unnamed: R3.1, U1.4 (RT)
unnamed: C5.1, U1.3 (SS)
unnamed: C4.1, R4.1, U1.1 (VC)

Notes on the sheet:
todo: switch capacitors for surface mount

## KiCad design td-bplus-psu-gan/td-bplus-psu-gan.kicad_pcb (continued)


Board: 2 copper layers, 40.0 x 40.0 mm, 27 parts (0 on the bottom side), 17 nets.

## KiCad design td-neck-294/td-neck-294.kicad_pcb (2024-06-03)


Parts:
C1, C3: 47uF; CP_Radial_D10.0mm_P5.00mm; Digikey 565-EKY-101ETD470MJC5SCT-ND
C2, C4, C5: 0.1uF; C_Disc_D8.0mm_W2.5mm_P5.00mm; Digikey BC1123CT-ND
C8: 680pF 2kV; C_Disc_D12.5mm_W5.0mm_P7.50mm; Digikey 445-CK45-B3FD681KYVNACT-ND
D1, D2, D3, D4, D5, D6: FDH400; D_DO-35_SOD27_P7.62mm_Horizontal_NoK; Digikey FDH400-ND
H1, H2: MountingHole; MountingHole_3.2mm_M3_ISO14580
HS1: Heatsink_Pad; Ohmite_RA-T2X-25E; Digikey RA-T2X-25E-ND
J1: Conn_01x05_Pin; JST_XH_B5B-XH-A_1x05_P2.50mm_Vertical; Digikey 455-B5B-XH-AM-ND
J2: Conn_01x04_Pin; JST_XH_B4B-XH-A_1x04_P2.50mm_Vertical; Digikey 455-B4B-XH-A-ND
J3: Conn_01x01_Pin; monitor_1p
J4: Wire; SolderWire-0.5sqmm_1x01_D0.9mm_OD2.3mm
JP1: SolderJumper_2_Bridged; SolderJumper-2_P1.3mm_Bridged_Pad1.0x1.5mm
L1, L2, L3: 0.1uH; L_Axial_L7.0mm_D3.3mm_P10.16mm_Horizontal_Fastron_MICC; Digikey M10147-ND
R1, R4, R5: 22; R_Axial_DIN0204_L3.6mm_D1.6mm_P5.08mm_Horizontal; Digikey S22CACT-ND
R2, R3, R6: 33; R_Axial_DIN0309_L9.0mm_D3.2mm_P12.70mm_Horizontal; Digikey 13-FKN-50JR-52-33RCT-ND
U1: LM2406; TO-220-11_P3.4x5.08mm_StaggerOdd_Lead4.85mm_Vertical
V1: GZS8-6-1

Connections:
+12V: C3.1, C5.1, J1.1, U1.10 (VBIAS)
/B_IN: J1.4, U1.8 (VIN3)
/G2: C8.1, J4.1, V1.8
/G_IN: J1.3, U1.9 (VIN2)
/H: J2.3, V1.4
/KB: R6.2, V1.3
/KG: R2.2, V1.9
/KR: R3.2, V1.7
/R_IN: J1.2, U1.11 (VIN1)
GND: C1.2, C2.2, C3.2, C4.2, C5.2, C8.2, D2.2 (A), D4.2 (A), D6.2 (A), HS1.1, J1.5, J2.4, J3.1, JP1.1 (A), U1.2 (GND), U1.4 (GND), U1.7 (GND), V1.0, V1.5
unnamed: D1.2 (A), D2.1 (K), L1.2, R3.1
unnamed: D3.2 (A), D4.1 (K), L2.2, R2.1
unnamed: D5.2 (A), D6.1 (K), L3.2, R6.1
unnamed: JP1.2 (B), V1.6
unnamed: L1.1, R4.2
unnamed: L2.1, R1.2
unnamed: L3.1, R5.2
unnamed: R4.1, U1.1 (VOUT1)
unnamed: R1.1, U1.3 (VOUT2)
unnamed: R5.1, U1.5 (VOUT3)
Vdrive: C1.1, C2.1, C4.1, D1.1 (K), D3.1 (K), D5.1 (K), J2.1, U1.6 (VCC)


Board: 2 copper layers, 103.0 x 55.0 mm, 31 parts (1 on the bottom side), 21 nets.

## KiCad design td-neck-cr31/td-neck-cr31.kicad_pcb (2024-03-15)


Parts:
C1: 330pF; C_Disc_D5.0mm_W2.5mm_P5.00mm; Digikey 445-180761-1-ND
C2, C4: 1000pF; C_Disc_D8.0mm_W2.5mm_P5.00mm; Digikey 445-180754-1-ND
C3: 10uF; CP_Radial_D6.3mm_P2.50mm; Digikey 399-6094-ND
C5, C7: 680pF; C_Disc_D5.0mm_W2.5mm_P5.00mm; Digikey 445-180765-1-ND
C6: 560pF; C_Disc_D5.0mm_W2.5mm_P5.00mm; Digikey 445-180765-1-ND
C8: 680pF 2kV; C_Disc_D12.5mm_W5.0mm_P7.50mm; Digikey 445-CK45-B3FD681KYVNACT-ND
H1, H2: MountingHole; MountingHole_3.2mm_M3_ISO14580
J1: Conn_01x05_Pin; JST_XH_B5B-XH-A_1x05_P2.50mm_Vertical; Digikey 455-B5B-XH-AM-ND
J2: Conn_01x04_Pin; JST_XH_B4B-XH-A_1x04_P2.50mm_Vertical; Digikey 455-B4B-XH-A-ND
J3: Conn_01x01_Pin; monitor_1p
J4: Wire; SolderWire-0.5sqmm_1x01_D0.9mm_OD2.3mm
L1: 150uH; L_Axial_L5.3mm_D2.2mm_P7.62mm_Horizontal_Vishay_IM-1; Digikey 118-78F151J-RC-ND
Q1, Q2, Q3: 2N6517TA; TO-92_Wide; Digikey 2N6517TACT-ND
R1: 180k; R_Axial_DIN0204_L3.6mm_D1.6mm_P5.08mm_Horizontal; Digikey S180KQCT-ND
R2: 22k; R_Axial_DIN0204_L3.6mm_D1.6mm_P5.08mm_Horizontal; Digikey S22KQCT-ND
R3, R5, R7: 15k; R_Axial_DIN0309_L9.0mm_D3.2mm_P12.70mm_Horizontal; Digikey A138268CT-ND
R4, R6, R8: 280; R_Axial_DIN0204_L3.6mm_D1.6mm_P5.08mm_Horizontal; Digikey S270QCT-ND
R9, R10, R11: 330; R_Axial_DIN0204_L3.6mm_D1.6mm_P5.08mm_Horizontal; Digikey S330QCT-ND
R12, R13, R14: 2.7k; R_Axial_DIN0207_L6.3mm_D2.5mm_P10.16mm_Horizontal; Digikey S2.7KHCT-ND
V1: GZS8-6-1

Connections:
/B_IN: J1.2, Q3.2 (B)
/G2: C8.1, J4.1, V1.8
/G_IN: J1.4, Q2.2 (B)
/H: J2.3, V1.4
/KB: R14.2, V1.3
/KG: R13.2, V1.9
/KR: R12.2, V1.7
/R_IN: J1.1, Q1.2 (B)
GND: C1.1, C2.2, C3.2, C4.2, C8.2, J2.4, J3.1, R2.2, V1.0, V1.5
GND1: C1.2, J1.3, R4.2, R6.2, R8.2
unnamed: C3.1, R1.2, R2.1, V1.6
unnamed: C4.1, L1.2, R3.1, R5.1, R7.1
unnamed: C5.2, C6.2, C7.2, J1.5, R9.2, R10.2, R11.2
unnamed: C2.1, J2.1, L1.1, R1.1
unnamed: Q1.3 (C), R3.2, R12.1
unnamed: C5.1, Q1.1 (E), R4.1, R9.1
unnamed: Q2.3 (C), R5.2, R13.1
unnamed: C6.1, Q2.1 (E), R6.1, R10.1
unnamed: Q3.3 (C), R7.2, R14.1
unnamed: C7.1, Q3.1 (E), R8.1, R11.1


Board: 2 copper layers, 88.0 x 55.0 mm, 33 parts (0 on the bottom side), 20 nets.

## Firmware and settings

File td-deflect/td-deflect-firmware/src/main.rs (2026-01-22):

#![no_main]
#![no_std]

mod adc;
mod horizontal;
mod serial;
mod v_class_d;
mod scan_fault;

use rtic::app;

#[app(device = stm32g4::stm32g474, peripherals = true, dispatchers = [EXTI0, EXTI1])]
mod app {
    use stm32g4::stm32g474::*;
    use cortex_m::asm::delay;
    use serde::{Deserialize};
    use heapless::spsc::{Queue, Producer, Consumer};
    use core::sync::atomic::{self, Ordering, AtomicBool};
    use core::panic::PanicInfo;
    use td_crt_protocol::*;
    use crate::adc::ADC;
    use crate::serial::{Serial, SerialProtocol};
    use crate::v_class_d::VDriveClassD;
    use crate::scan_fault::ScanFault;
    use crate::horizontal::HOTDriver;

    pub const AHB_CLOCK: u32 = 170_000_000;
    pub const APB2_CLOCK: u32 = AHB_CLOCK;

    pub const MIN_H_FREQ: u32 = 15000;
    pub const MAX_H_FREQ: u32 = 16000;
    #[allow(unused)]
    pub const MAX_H_PERIOD: u32 = AHB_CLOCK / MIN_H_FREQ;
    pub const MIN_H_PERIOD: u32 = AHB_CLOCK / MAX_H_FREQ;

    const DAC_MIDPOINT: i32 = 2047;

    static FAULTED: AtomicBool = AtomicBool::new(false);

    /// Immediately blanks the video signal.
    /// Used in case of deflection failure to prevent burn-in.
    fn fault_blank() {
        // read-modify-write is a bit unfortunate here
        unsafe { (*GPIOC::ptr()).odr().modify(|_,w| {w.odr14().bit(true)}); }
    }

    #[inline(never)]
    #[panic_handler]
    fn panic(_info: &PanicInfo) -> ! {
        FAULTED.store(true, Ordering::Relaxed);
        fault_blank();
        loop {
            atomic::compiler_fence(Ordering::SeqCst);
        }
    }

    #[shared]
    struct Shared {
        serial_protocol: SerialProtocol,
    }
    #[local]
    struct Local {
        gpioa: GPIOA,
        gpiob: GPIOB,
        gpioc: GPIOC,
        gpioe: GPIOE,
        v_drive: VDrive,
        v_drive_classd: VDriveClassD,
        hot_driver: HOTDriver,
        hsync_capture: HSyncCapture,
        crt_state: CRTState,
        crt_stats_live: CRTStats,
        adc: ADC,
        config: Config,
        config_queue_in: Producer<'static, Config, 2>,
        config_queue_out: Consumer<'static, Config, 2>,
    }
    #[init]
    fn init(cx: init::Context) -> (Shared, Local) {
        let s = cx.device;

        let rcc = s.RCC;
        let gpioa = s.GPIOA;
        let gpiob = s.GPIOB;
        let gpioc = s.GPIOC;
        let gpioe = s.GPIOE;
        let dac = s.DAC1;
        let flash = s.FLASH;
        let pwr = s.PWR;
        let usart1 = s.USART1;
        let adc1 = s.ADC1;
        let adc2 = s.ADC2;

        // enable pwr clock
        rcc.apb1enr1().write(|w| { w.pwren().bit(true) });

        // set maximum flash delay
        flash.acr().write(|w| {
            unsafe {
                w.prften().bit(true).dcen().set_bit().icen().set_bit().latency().bits(0b0100)
            }
        });
        // switch to 1.28v core voltage
        pwr.cr5().modify(|_,w| { w.r1mode().clear_bit() });
        // 16mhz hse / 4 * 75 = 300mhz pll output
        // divide by 2 for 170mhz main system clock
        rcc.pllcfgr().write(|w| { unsafe {
            w.pllsrc().bits(0b11).pllm().bits(3).plln().bits(85).pllren().set_bit()
        }});
        //enable hse and pll
        rcc.cr().write(|w| {
            w.hseon().set_bit().hsebyp().set_bit().pllon().set_bit()
        });
        // wait for pll lock
        while !rcc.cr().read().pllrdy().bit() {};
        // apb2 system, apb1 system, switch to pll as clock source
        // temporarily run ahb at clock rate / 2
        rcc.cfgr().write(|w| { unsafe {
            w.ppre2().bits(0b000).ppre1().bits(0b000).hpre().div2().sw().pll()}
        });
        while rcc.cfgr().read().sws().bits() != 0b11 {};
        delay(170); // wait 1us for stabilization
        rcc.cfgr().modify(|_,w| { w.hpre().div1() });

        rcc.ahb2enr().modify(|_,w| { w.gpioaen().bit(true) });
        rcc.ahb2enr().modify(|_,w| { w.gpioben().bit(true) });
        rcc.ahb2enr().modify(|_,w| { w.gpiocen().bit(true) });
        rcc.ahb2enr().modify(|_,w| { w.gpioeen().bit(true) });
        rcc.apb2enr().modify(|_,w| { w.tim1en().bit(true) });
        rcc.ahb2enr().modify(|_,w| { w.dac1en().bit(true) });
        //rcc.apb2enr.modify(|_,w| { w.tim10en().bit(true) });
        rcc.apb1enr1().modify(|_,w| { w.tim3en().bit(true) });
        rcc.apb1enr1().modify(|_,w| { w.tim4en().bit(true) });

        // HOT output
        // new TIM1 CH3 connected lines
        gpioa.afrh().modify(|_,w| { w.afrh10().af6() });
        gpioa.moder().modify(|_,w| { w.moder10().alternate() });

        // hsync input
        gpioa.afrl().modify(|_,w| { w.afrl6().af2() });
        gpioa.moder().modify(|_,w| { w. moder6().alternate() });
        // loopback signal from H.PIN OUT for phase measurement
        //gpiob.afrl.modify(|_,w| {w.afrl1().af2() }); // TIM3_CH4
        //gpiob.moder.modify(|_,w| {w.moder1().alternate() });

        // serial input/output
        let serial = Serial::new(usart1, &gpioc, &rcc);
        let serial_protocol = SerialProtocol::new(serial);

        // vertical sync inputs
        gpiob.moder().modify(|_,w| {w.moder0().input()});
        gpiob.pupdr().modify(|_,w| {w.pupdr0().pull_up()});
        gpioa.moder().modify(|_,w| {w.moder7().input()});
        gpioa.pupdr().modify(|_,w| {w.pupdr7().pull_up()});
        //gpioc.moder.modify(|_,w| {w.moder15().input()}); // oddeven

        // horizontal PWM
        gpioa.afrh().modify(|_,w| {w.afrh8().af6()});
        gpioa.moder().modify(|_,w| {w.moder8().alternate()});
        gpiob.afrh().modify(|_,w| {w.afrh13().af6()});
        gpiob.moder().modify(|_,w| {w.moder13().alternate()});

        // hv flyback transistor output
        gpiob.afrl().modify(|_,w| {w.afrl6().af2()});
        gpiob.moder().modify(|_,w| {w.moder6().alternate()});

        // blanking output to lm1205
        gpioe.moder().modify(|_,w| {w.moder7().output()});
        gpioe.odr().modify(|_,w| {w.odr7().bit(true)}); // start up with blanking enabled

        // S-cap lines
        // start with all S caps on, will change later in hsync timer interrupt
        gpiob.odr().modify(|_,w| { w.odr9().high() });
        gpioc.odr().modify(|_,w| { w.odr1().high().odr2().high().odr3().high() });
        gpiob.moder().modify(|_,w| { w.moder9().output() });
        gpioc.moder().modify(|_,w| { w.moder1().output().moder2().output().moder3().output() });

        // Vertical DAC output
        gpioa.moder().modify(|_,w| { w.moder4().analog() });
        // enable vertical SSR
        gpioc.odr().modify(|_,w| { w.odr13().set_bit() });
        gpioc.moder().modify(|_,w| { w.moder13().output() });

        // heater
        gpiob.odr().modify(|_,w| { w.odr4().high() });
        gpiob.moder().modify(|_,w| { w.moder4().output() });

        let adc = ADC::new(&s.ADC12_COMMON, adc1, adc2, &rcc, &gpioa, &gpiob, &gpioc);
        let v_drive = VDrive::new(dac);

        let v_drive_classd = VDriveClassD::new(&rcc, &gpioc, &s.HRTIM_COMMON, &s.HRTIM_MASTER, s.HRTIM_TIME, s.HRTIM_TIMF);

        let mut hot_driver = HOTDriver::new(s.TIM1, s.TIM4);
        let hsync_capture = HSyncCapture::new(s.TIM3);
        hot_driver.set_frequency(15700);

        // configure the system timer to wrap around every second
        //syst.set_clock_source(SystClkSource::Core);
        //syst.set_reload(AHB_CLOCK); // once a second
        //syst.enable_counter();
        let crt_stats_live = CRTStats::default();
        let crt_state = CRTState::default();
        let config = Config { crt: CRT_CONFIG_NEC_KD_252, input: InputConfig { h_size: 0.95, h_phase: 0.05 } };

        // config queue for purposes of "double buffering" config
        static mut CONFIG_QUEUE: Queue<Config, 2> = Queue::new();
        // unsafe: we can fix this with rtic 0.6
        let (config_queue_in, config_queue_out) = unsafe { CONFIG_QUEUE.split() };
        (Shared {
            serial_protocol,
        }, Local {
            gpioa,
            gpiob,
            gpioc,
            gpioe,
            config_queue_out,
            config_queue_in,
            adc,
            v_drive,
            v_drive_classd,
            hot_driver,
            hsync_capture,
            crt_stats_live,
            crt_state,
            config,
        })
    }

    // internal hsync timer interrupt
    #[inline(never)]
    #[link_section = ".data.TIM1_UP_TIM16"]
    #[task(binds = TIM1_UP_TIM16, local = [v_drive, v_drive_classd, gpioa, gpiob, gpioc, gpioe, hot_driver, hsync_capture,  crt_state, config, crt_stats_live, adc, config_queue_out], priority = 15)]
    fn tim1_up_tim16(cx: tim1_up_tim16::Context) {
        let crt_state = cx.local.crt_state;
        let current_scanline = &mut crt_state.current_scanline;
        let v_drive = cx.local.v_drive;
        let v_drive_classd = cx.local.v_drive_classd;
        let gpioa = cx.local.gpioa;
        let gpiob = cx.local.gpiob;
        let gpioc = cx.local.gpioc;
        let gpioe = cx.local.gpioe;
        let hot_driver = cx.local.hot_driver;
        let hsync_capture = cx.local.hsync_capture;
        let crt_stats = cx.local.crt_stats_live;
        let adc = cx.local.adc;
        let config = cx.local.config;

        hsync_capture.update();
        atomic::compiler_fence(Ordering::SeqCst);
        v_drive.trigger();

        let input_period = hsync_capture.get_period_averaged();
        let output_period = hot_driver.get_period() as i32;
        // if we are really far away frequency wise, just ignore this sync entirely
        if (output_period - input_period as i32).abs() > ((MIN_H_PERIOD as i32) / 10){
            // yolo
        } else {
            let error = hsync_capture.get_phase_error_averaged() + (config.input.h_phase * output_period as f32);
            let FEEDBACK_GAIN = 0.001;
            let fb = if (*current_scanline < 10) || (*current_scanline > 250) {
                (error * FEEDBACK_GAIN).clamp(-3.0, 3.0)
            } else {
                (error * FEEDBACK_GAIN).clamp(-1.0, 1.0)
                  //0.0
            };
            //let fb_quantized = libm::roundf(fb) as i32;
            //let error_mag = 0;
            let new_period = input_period - fb;
            hot_driver.set_period_float(new_period);
            //hsync_capture.apply_phase_feedforward(fb_quantized);
        }

        hot_driver.duty_setpoint = config.input.h_size;
        hot_driver.update();

        let VERTICAL_MAX_AMPS = 1.0;
        let VERTICAL_BLANKING_SCANLINES = 20;
        // vertical advance
        // vertical counter
        let vga_vsync = gpiob.idr().read().idr0().bit(); // vga sync input
        let separated_vsync = gpioa.idr().read().idr7().bit(); // composite sync input
        //let vsync = vga_vsync & separated_vsync;
        let vsync = separated_vsync;
        let odd = gpioc.idr().read().idr15().bit();
        // negative edge triggered
        let total_lines = 262;
        let center_line = total_lines / 2;
        if (vsync == false) && (crt_state.previous_vga_vsync == true) {
            crt_stats.v_lines = *current_scanline as u16;
            crt_stats.odd = odd;
            *current_scanline = 0;
        }
        crt_state.previous_vga_vsync = vsync;
        if *current_scanline >= (total_lines + 10) { *current_scanline = 0 };
        // handle vertical blanking
        if *current_scanline >= VERTICAL_BLANKING_SCANLINES {
            if !FAULTED.load(Ordering::Relaxed) &&
                !crt_state.v_scan_fault.get_fault() {
                gpioe.odr().modify(|_,w| {w.odr7().bit(true)}); // show image
            }
        } else {
            gpioe.odr().modify(|_,w| {w.odr7().bit(false)}); // blank image
        }
        //gpioe.odr().modify(|_,w| {w.odr7().bit(true)}); // show image

        // convert scanline to a (+1, -1) range coordinate (+1 is top of screen)
        let horizontal_pos_coordinate = (((if *current_scanline > 253 { 0 } else { *current_scanline }) - center_line) as f32 + if odd { 0.0 } else { -0.5 }) / (total_lines as f32) * -2.0;
        let vertical_linearity = config.crt.vertical_linearity;
        let vertical_linearity_scale = 1.0 / libm::atanf(1.0 * vertical_linearity);
        let horizontal_coordinate_corrected = if vertical_linearity < 0.1 {
            horizontal_pos_coordinate
        } else {
            libm::atanf(horizontal_pos_coordinate * vertical_linearity) * vertical_linearity_scale
        };
        let horizontal_amps = (horizontal_coordinate_corrected * config.crt.v_mag_amps + config.crt.v_offset_amps).clamp(-1.0*VERTICAL_MAX_AMPS, VERTICAL_MAX_AMPS);
        v_drive.set_current(horizontal_amps);
        v_drive_classd.set_current(horizontal_amps);
        v_drive.update();
        v_drive_classd.update(1.0/15700.0); // TODO: use real timestep value

        // update stats
        crt_stats.h_input_period = input_period as i32;
        crt_stats.h_input_period_max = crt_stats.h_input_period_max.max(input_period as i32);
        if crt_stats.h_input_period_min == 0 {
            crt_stats.h_input_period_min = input_period as i32;
        }
        crt_stats.h_input_period_min = crt_stats.h_input_period_min.min(input_period as i32);
        crt_stats.h_output_period = output_period;
        crt_stats.h_output_period_max = crt_stats.h_output_period_max.max(output_period);
        if crt_stats.h_output_period_min == 0 {
            crt_stats.h_output_period_min = output_period;
        }
        crt_stats.h_output_period_min = crt_stats.h_output_period_min.min(output_period);

        // perform analog reads
        // todo: trigger these with timer
        let adc_horiz_data = adc.read_all_horiz();
        crt_state.v_scan_fault.push(adc_horiz_data.vertical_class_d_current_post);
        crt_stats.s_voltage = adc_horiz_data.s_voltage;
        let _ = crt_stats.vertical_class_d_current_per_scanline.push(adc_horiz_data.vertical_class_d_current_post);
        let _ = crt_stats.vertical_target_current_per_scanline.push(horizontal_amps);

        // update s capacitors
        gpiob.odr().modify(|_,w| { w.odr9().bit((config.crt.s_cap & 0b1000) == 0) });
        gpioc.odr().modify(|_,w| { w.odr1().bit((config.crt.s_cap & 0b0100) == 0)
                                 .odr2().bit((config.crt.s_cap & 0b0010) == 0)
                                 .odr3().bit((config.crt.s_cap & 0b0001) == 0) });

        crt_stats.faulted = FAULTED.load(Ordering::Relaxed);

        // send stats updates over serial
        if *current_scanline == 0 {
            let _ = send_stats::spawn(crt_stats.clone());
            *crt_stats = CRTStats::default(); // reset for a new frame
        }
        *current_scanline += 1;

        // update config if there's one in the queue
        if let Some(new_config) = cx.local.config_queue_out.dequeue() {
            *config = new_config;
        }

        // clear interrupt flag for tim10
        hot_driver.tp.sr().write(|w| w.uif().bit(false));
    }

    #[task(binds = USART1, local = [config_queue_in], shared = [serial_protocol], priority = 2)]
    fn serial_interrupt(mut c: serial_interrupt::Context) {
        // TODO: convert tx to use fifo interrupts
        // TODO: convert rx to use fifo interrupts
        let config_queue_in = c.local.config_queue_in;
        c.shared.serial_protocol.lock(|serial_protocol| {
            while serial_protocol.serial.usart.isr().read().rxne().bit() {
                serial_protocol.process_byte(config_queue_in);
            }
            if serial_protocol.serial.usart.isr().read().txe().bit() {
                if let Some(c) = serial_protocol.serial.send_queue.pop_front() {
                    serial_protocol.serial.usart.tdr().write(|w| { unsafe{ w.tdr().bits((c).into()) } });
                } else {
                    serial_protocol.serial.usart.cr1().modify(|_,w| { w.txeie().clear_bit() });
                }
            }
            serial_protocol.serial.usart.icr().write(|w| { w.orecf().set_bit() });
        });
    }

    #[task(shared = [serial_protocol], priority = 1)]
    async fn send_stats(mut c: send_stats::Context, crt_stats: CRTStats) {
        let mut json_stats: [u8; 8192] = [0; 8192];
        let mut json_stats_len = 0;
        if let Ok(c) = serde_json_core::to_slice(&crt_stats, &mut json_stats) { json_stats_len = c };
        c.shared.serial_protocol.lock(|serial_protocol| {
            if json_stats_len < json_stats.len() {
                json_stats[json_stats_len] = b'\n';
                let _ = serial_protocol.serial.write_queued(&json_stats[..json_stats_len + 1]);
            }
        });
    }


    #[idle()]
    fn idle(_cx: idle::Context) -> ! {
        loop {
              rtic::export::wfi()
        }
    }

    #[derive(Default)]
    pub struct CRTState {
        current_scanline: i32,
        previous_vga_vsync: bool, // used to detect negative edge sync
        v_scan_fault: ScanFault,
    }

    #[allow(unused)]
    static CRT_CONFIG_PANASONIC_S901Y: CRTConfig = CRTConfig {
        v_mag_amps: 0.414,
        v_offset_amps: 0.0,
        vertical_linearity: 0.55,
        s_cap: 1,
    };

    #[allow(unused)]
    static CRT_CONFIG_PANASONIC_CTN_1061R: CRTConfig = CRTConfig {
        v_mag_amps: 0.53,
        v_offset_amps: 0.0,
        vertical_linearity: 0.55,
        s_cap: 1,
    };

    #[allow(unused)]
    static CRT_CONFIG_REALILSTIC_16_108: CRTConfig = CRTConfig {
        v_mag_amps: 0.23,
        v_offset_amps: 0.0,
        vertical_linearity: 0.55,
        s_cap: 1,
    };

    static CRT_CONFIG_NEC_KD_252: CRTConfig = CRTConfig {
        v_mag_amps: 0.16,
        v_offset_amps: 0.00,
        vertical_linearity: 0.55,
        s_cap: 1,
    };

    /// Complete runtime configuration, both CRT config + input config
    #[derive(Copy, Clone, Deserialize)]
    pub struct Config {
        crt: CRTConfig,
        input: InputConfig,
    }

    pub struct HSyncCapture {
        t: TIM3,
        previous_input_periods: [u32; HSyncCapture::AVERAGED_INPUT_PERIODS],
        previous_input_periods_index: usize,
        previous_phase_errors: [i32; HSyncCapture::AVERAGED_PHASE_ERRORS],
        previous_phase_errors_index: usize,
    }

    impl HSyncCapture {
        const AVERAGED_INPUT_PERIODS: usize = 256;
        const AVERAGED_PHASE_ERRORS: usize = 4;
        fn new(t: TIM3) -> HSyncCapture {
            t.ccmr1_output().write(|w| { unsafe { w.bits(0b0000_00_10_0000_00_01)}});
            t.ccmr2_input().write(|w| { unsafe { w.cc4s().bits(0b01) } });
            t.smcr().write(|w| { unsafe { w.ts().bits(0b101).sms().bits(0b0100) }});
            // CH1 is configured to reset the counter and measure H period
            // CH4 is configured for capture to measure H phase error
            t.ccer().write(|w| { w.cc1p().set_bit().cc1e().set_bit().cc4p().clear_bit().cc4np().clear_bit().cc4e().set_bit() });
            t.cr1().write(|w| { w.cen().set_bit() });
            HSyncCapture {
                t,
                previous_input_periods: [MAX_H_PERIOD; HSyncCapture::AVERAGED_INPUT_PERIODS],
                previous_input_periods_index: 0,
                previous_phase_errors: [0; HSyncCapture::AVERAGED_PHASE_ERRORS],
                previous_phase_errors_index: 0,
            }
        }
        #[inline(always)]
        fn get_cycles_since_sync(&self) -> u32 {
            // hardware method
            //self.t.ccr4().read().ccr().bits() as u32
            // software method (relies on interrupt latency being exact)
            (self.t.cnt().read().cnt().bits() & 0xFFFF) as u32
        }
        #[inline(always)]
        fn update(&mut self) {
            let cycles_since_sync = self.get_cycles_since_sync() as i32; // important: must be executed first
            atomic::compiler_fence(Ordering::SeqCst);
            let input_period = self.get_period() as i32;
            let previous_input_period = self.previous_input_periods[self.previous_input_periods_index] as i32;
            if (previous_input_period - input_period).abs() > ((MIN_H_PERIOD as i32) / 10) {
                // don't update any averages for outliers
            } else {
                self.previous_input_periods[self.previous_input_periods_index] = input_period as u32;
                self.previous_input_periods_index = (self.previous_input_periods_index + 1) % HSyncCapture::AVERAGED_INPUT_PERIODS;
                let error = if cycles_since_sync < (input_period as i32 / 2) {
                    cycles_since_sync.max(64)
                } else {
                    (cycles_since_sync - input_period as i32).min(-16)
                };
                self.previous_phase_errors[self.previous_phase_errors_index] = error;
                self.previous_phase_errors_index = (self.previous_phase_errors_index + 1) % HSyncCapture::AVERAGED_PHASE_ERRORS;
            }
        }
        fn _apply_phase_feedforward(&mut self, b: i32) {
            self.previous_phase_errors[self.previous_phase_errors_index] -= b * 1;
        }
        fn get_phase_error_averaged(&self) -> f32 {
            let mut avg: f32 = 0.0;
            for a in self.previous_phase_errors {
                avg += a as f32;
            }
            avg /= HSyncCapture::AVERAGED_PHASE_ERRORS as f32;
            return avg;
        }
        fn get_period_averaged(&self) -> f32 {
            let mut avg = 0.0;
            for a in self.previous_input_periods {
                avg += a as f32;
            }
            avg /= HSyncCapture::AVERAGED_INPUT_PERIODS as f32;
            return avg;
        }
        fn get_period(&self) -> u32 {
            // not entirely sure why this is +2 but it seems to be better
            self.t.ccr1().read().ccr().bits() as u32 + 2
        }
    }

    pub struct VDrive {
        dac: DAC1,
        setpoint: f32,
        accumulator: f32,
    }
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

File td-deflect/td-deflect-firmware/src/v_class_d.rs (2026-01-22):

use stm32g4::stm32g474::*;

pub struct VDriveClassD {
    hrte: HRTIM_TIME,
    hrtf: HRTIM_TIMF,
    current_setpoint: f32,
    current_previous: f32,
}

const DEADTIME: u16 = 60;

const PERIOD: u16 = 0x2000;
const INPUT_VOLTAGE: f32 = 30.0;
const V_RESISTANCE: f32 = 50.6; //13.243;
const V_INDUCTANCE: f32 =  115.0e-3; //83.35e-3;//27.86e-3;
const MIDPOINT: f32 = (PERIOD as f32) / 2.0;
// maximum duty cycle controlled by bootstrap for high side mosfet
// make min duty cycle symmetrical to avoid creating a dc component
const DUTY_CYCLE_MIN: f32 = 0.20;
const DUTY_CYCLE_MAX: f32 = 0.80;
const COUNTS_MIN: u16 = (DUTY_CYCLE_MIN * PERIOD as f32) as u16;
const COUNTS_MAX: u16 = (DUTY_CYCLE_MAX * PERIOD as f32) as u16;


impl VDriveClassD {
    pub fn new(rcc: &RCC, gpioc: &GPIOC, hrc: &HRTIM_COMMON, hrm: &HRTIM_MASTER, hrte: HRTIM_TIME, hrtf: HRTIM_TIMF) -> VDriveClassD {
        rcc.apb2enr().modify(|_,w| { w.hrtim1en().enabled() });
        // start hrtim calibration
        hrc.dllcr().modify(|_,w| { w.cal().set_bit() });
        while !hrc.isr().read().dllrdy().bit() {};
        hrte.outer().modify(|_,w| { unsafe { w.pol1().clear_bit()
                                             .pol2().clear_bit()
                                             .fault1().bits(0b10)
                                             .fault2().bits(0b10)
                                             .dten().set_bit() } });
        hrtf.outfr().modify(|_,w| { unsafe { w.pol1().clear_bit()
                                             .pol2().clear_bit()
                                             .fault1().bits(0b10)
                                             .fault2().bits(0b10)
                                             .dten().set_bit() } });
        hrte.dter().modify(|_,w| { unsafe { w.dtrx().bits(DEADTIME).dtfx().bits(DEADTIME) } });
        hrtf.dtfr().modify(|_,w| { unsafe { w.dtrx().bits(DEADTIME).dtfx().bits(DEADTIME) } });
        hrte.perer().write(|w| { unsafe { w.perx().bits(PERIOD) } });
        hrtf.perfr().write(|w| { unsafe { w.perx().bits(PERIOD) } });
        hrte.sete1r().modify(|_,w| { w.cmp1().set_bit() });
        hrte.rste1r().modify(|_,w| { w.per().set_bit() });
        hrtf.setf1r().modify(|_,w| { w.cmp1().set_bit() });
        hrtf.rstf1r().modify(|_,w| { w.per().set_bit() });
        hrte.timecr().modify(|_,w| { w.cont().set_bit().preen().set_bit().tx_rstu().set_bit() });
        hrtf.timfcr().modify(|_,w| { w.cont().set_bit().preen().set_bit().tx_rstu().set_bit() });
        hrte.cmp1er().write(|w| { unsafe { w.cmp1x().bits(MIDPOINT as u16) } });
        hrtf.cmp1fr().write(|w| { unsafe { w.cmp1x().bits(MIDPOINT as u16) } });
        hrm.mcr().modify(|_,w| { w.tecen().set_bit().tfcen().set_bit() });
        gpioc.afrl().modify(|_,w| { w.afrl6().af13()
                                    .afrl7().af13() });
        gpioc.afrh().modify(|_,w| { w.afrh8().af3()
                                    .afrh9().af3() });
        gpioc.moder().modify(|_,w| { w
                                     .moder6().alternate()
                                     .moder7().alternate()
                                     .moder8().alternate()
                                     .moder9().alternate()
        });
        hrc.oenr().write(|w| { w.te1oen().set_bit()
                                .te2oen().set_bit()
                                .tf1oen().set_bit()
                                .tf2oen().set_bit() });
        VDriveClassD {
            hrte,
            hrtf,
            current_setpoint: 0.0,
            current_previous: 0.0
        }
    }
    pub fn set_current(&mut self, current: f32) {
        self.current_setpoint = current;
    }
    pub fn update(&mut self, timestep: f32) {
        let current_delta = self.current_setpoint - self.current_previous;
        let target_voltage = self.current_setpoint * V_RESISTANCE + current_delta * V_INDUCTANCE / timestep;
        let target_voltage_a = target_voltage*0.5;
        let target_voltage_b = target_voltage*-0.5;
        let volts_per_count = INPUT_VOLTAGE / PERIOD as f32;
        let target_counts_a = (MIDPOINT + target_voltage_a / volts_per_count) as u16;
        let target_counts_b = (MIDPOINT + target_voltage_b / volts_per_count) as u16;
        let clamped_counts_a = target_counts_a.clamp(COUNTS_MIN, COUNTS_MAX);
        let clamped_counts_b = target_counts_b.clamp(COUNTS_MIN, COUNTS_MAX);
        self.hrte.cmp1er().write(|w| { unsafe { w.cmp1x().bits(clamped_counts_a) } });
        self.hrtf.cmp1fr().write(|w| { unsafe { w.cmp1x().bits(clamped_counts_b) } });
        // because during retrace we are likely duty cycle limited,
        // we compute the state by going backwards
        let real_voltage_a = (clamped_counts_a as f32 - MIDPOINT) * volts_per_count;
        let real_voltage_b = (clamped_counts_b as f32 - MIDPOINT) * volts_per_count;
        let real_voltage = real_voltage_a - real_voltage_b;
        // V = L di/dt
        // V*dt/L = di
        self.current_previous += (real_voltage - self.current_previous * V_RESISTANCE)*timestep/V_INDUCTANCE;
    }
}

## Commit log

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2018-12-27 I have no idea what I'm doing
    [_saved_uc.sch, td-deflect.kicad_pcb, td-deflect.sch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]
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2019-01-27 Add 3d printed bracket
    [td-rgb-bracket.fcstd, td-rgb-bracket.stl]
2019-02-07 Update footprint for DE-15 connector to correct pin row spacing
    [iicd15s13e6gv00lf.igs, td-rgb.kicad_pcb]
2019-02-07 Correct DE-15 placement on PCB to bring closer to original design
    [td-rgb.kicad_pcb]
2019-10-08 drop some of the old GaNs
    [td-deflect.sch, uc.sch]
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2019-10-10 Update firmware to not use a git version of hal
    [td-deflect.sch, uc.sch]
2019-10-27 add lots of stuff
    [power_supply.sch, rgb.sch, td-deflect.kicad_pcb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]
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2019-12-03 Fix some part #s
    [rgb.sch, uc.sch]
2019-12-03 Fix vertical deflection output wiring
    [td-deflect.sch]
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2021-07-06 180v fixes
    [td-180v.kicad_pcb, td-180v.sch]
2021-07-06 more fixes
    [td-180v.kicad_pcb, td-180v.sch]
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2021-08-14 add output for vertical ssr
    [td-hv.kicad_pcb]
2021-08-14 fix warning in gui
    [main.rs]
2021-08-15 temporary fix for bad bootstrap diode
    [main.rs]
2021-08-17 Convert schematic to newer nightly format
    [_saved_uc.sch, power_supply.kicad_sch, power_supply.sch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]
2021-08-17 convert deflect pcb to newer nightly
    [td-deflect.kicad_pcb]
2021-08-17 add todos to schematic
    [power_supply.kicad_sch, rgb.kicad_sch, td-deflect.kicad_sch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]
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2021-08-22 implement phase error averaging
    [main.rs]
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2021-08-25 switch HOT to use TIM1 CH4
    [uc.kicad_sch]
2021-08-26 Add hardware phase error capture
    [uc.kicad_sch]
2021-08-26 add super basic vertical linearity correction
    [main.rs]
2021-08-31 Add error diffusion for vertical drive
    [main.rs]
2021-08-31 add error diffusion to h period
    [main.rs]
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2021-09-13 pn updates for hv
    [td-hv.sch]
2021-09-19 fix a few lints
    [main.rs]
2021-09-20 fix CRT stats clearing per field
    [main.rs]
2021-09-25 td-hv bugfixes
    [td-hv.sch]
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2021-12-11 add missing sch file
    [color_channel.sch]
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2021-12-18 update td-rgbinput to kicad 6.0.0-rc2
    [color_channel.kicad_sch, td-rgbinput.kicad_sch, td-rgbinput.sch]
2021-12-18 fix todos
    [color_channel.kicad_sch, td-rgbinput.kicad_sch]
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2021-12-19 fill a few extra areas
    [td-rgbinput.kicad_pcb]
2021-12-19 fix zones
    [td-rgbinput.kicad_pcb]
2021-12-19 update footprints from kicad 6 library
    [td-rgbinput.kicad_pcb]
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2021-12-19 remove old format schematic
    [color_channel.sch]
2021-12-19 convert td-hv to kicad 6
    [td-hv.kicad_sch, td-hv.sch]
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2021-12-30 add missing td-180v file
2021-12-30 update td-hv schematic to match currently built circuit
    [td-hv.kicad_sch]
2021-12-30 attach vcc to the 3845
    [td-hv.kicad_sch]
2021-12-30 change part number of ucc38c45
    [td-hv.kicad_sch]
2021-12-30 switch tlc272 power source to 5v
    [td-hv.kicad_sch]
2022-02-14 update td-rgbinput to reflect constructed circuit
    [color_channel.kicad_sch, td-rgbinput.kicad_sch]
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2022-12-23 update td-deflect kicad version
    [power_supply.kicad_sch, rgb.kicad_sch, td-deflect.kicad_sch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]
2022-12-23 update some transistors, remove current sense amp
    [power_supply.kicad_sch, td-deflect.kicad_sch]
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2022-12-26 switch to newer sic mosfet
    [td-deflect.kicad_sch]
2022-12-26 replace S capacitors
    [td-deflect.kicad_sch]
2022-12-26 remove recirculating schottky diode
    [td-deflect.kicad_sch]
2022-12-26 add gate resistors to top drive
    [td-deflect.kicad_sch]
2022-12-26 switch b+ diode to sic
    [power_supply.kicad_sch, td-deflect.kicad_sch]
2022-12-27 switch ti to rohm switching power ic
    [power_supply.kicad_sch, td-deflect.kicad_sch]
2022-12-27 replace negative supply with coupled inductor
    [power_supply.kicad_sch, td-deflect.kicad_sch]
2022-12-28 add switching heater supply
    [power_supply.kicad_sch, td-deflect.kicad_sch]
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2022-12-28 current measurement for h
    [td-deflect.kicad_sch, uc.kicad_sch]
2022-12-28 make bootstrap circuit not bootstrap as much
    [td-deflect.kicad_sch]
2023-01-02 add class d vertical amp
    [td-deflect.kicad_sch, v_classd.kicad_sch]
2023-01-02 switch to smt hot
    [td-deflect.kicad_sch, uc.kicad_sch, v_classd.kicad_sch]
2023-01-03 switch to new sic for hv
    [power_supply.kicad_sch, td-deflect.kicad_sch]
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2023-01-03 add hv protect and more sense lines
    [power_supply.kicad_sch, td-deflect.kicad_sch, uc.kicad_sch]
2023-01-04 add connector for power
    [power_supply.kicad_sch, td-deflect.kicad_sch, uc.kicad_sch]
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2023-01-25 connect more uc pins
    [td-deflect.kicad_sch, uc.kicad_sch, v_classd.kicad_sch]
2023-04-24 convert schematic to kicad 7 format
    [degauss.kicad_sch, power_supply.kicad_sch, rgb.kicad_sch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]
2023-04-24 switch to kicad official uc symbol
    [uc.kicad_sch]
2023-04-24 update kicad format and move flyback to separate sheet
    [degauss.kicad_sch, flyback.kicad_sch, power_supply.kicad_sch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]
2023-04-24 Add independent cathode supply
    [power_supply.kicad_sch]
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2023-09-20 drop current sense note
    [td-deflect.kicad_sch]
2023-09-20 add separate analog power supply
    [uc.kicad_sch]
2023-09-20 modify flyback feedback mechanism
    [flyback.kicad_sch, uc.kicad_sch]
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2023-09-21 small bugfix
    [flyback.kicad_sch, power_supply.kicad_sch, rgb.kicad_sch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]
2023-09-22 new version of td-hv, microcontroller control only
    [flyback.kicad_sch, td-hv.kicad_sch]
2023-09-22 switch to new 0805 footprint
    [degauss.kicad_sch, flyback.kicad_sch, power_supply.kicad_sch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]
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2023-09-30 update td-hv for v2.0
    [td-hv.kicad_pcb]
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2023-10-04 update lm1205 to v1.0
    [rgb.kicad_sch, td-rgbinput-lm1205.kicad_pcb, td-rgbinput-lm1205.kicad_sch]
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2023-10-07 small lm1205 fixup
    [td-rgbinput-lm1205.kicad_pcb]
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2023-10-08 add split rail psu
    [td-split-rail-psu.kicad_pcb, td-split-rail-psu.kicad_sch]
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2023-11-27 finish split rail psu pcb
    [td-split-rail-psu.kicad_pcb]
2023-11-27 switch to 100 pin tqfp microcontroller
    [uc.kicad_sch, v_classd.kicad_sch]
2023-11-27 use off board bplus h supply
    [power_supply.kicad_sch, td-deflect.kicad_sch]
2023-11-27 use off board f and c supply
    [power_supply.kicad_sch]
2023-11-27 use off board +12/-12/+6v supplies
    [power_supply.kicad_sch]
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2023-11-29 fix drc errors
    [degauss.kicad_sch, flyback.kicad_sch, power_supply.kicad_sch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]
2023-11-29 fix remaining erc errors
    [degauss.kicad_sch, flyback.kicad_sch, power_supply.kicad_sch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]
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2024-01-26 remove bad digikey pn
    [td-rgbinput-lm1205.kicad_sch]
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2024-02-24 fix some more gpios
    [main.rs, v_class_d.rs]
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2024-03-02 fix system clock in gui
    [main.rs]
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2024-09-30 Migrate to rtic2
    this temporarily loses interrupt execution from ram support
    [rgb.kicad_sch, td-rgbinput-lm1205.kicad_sch]
2024-10-01 fix occasional status message corruption
    [main.rs]
2024-10-04 switch tx to bounded queue to avoid lag
    [main.rs]
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2025-07-13 do some basic fixes
    [flyback.kicad_sch, td-hv.kicad_pcb]
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2025-07-13 swap to recom modules for 3.3V rails
    [uc.kicad_sch]
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2025-10-03 Update bplus psu to have better caps and pot facing the right dir
    [td-bplus-psu.kicad_pcb, td-bplus-psu.kicad_sch]
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2025-10-03 Adjust td-hv pin spacing and add a bypass jumper
    [flyback.kicad_sch, td-hv.kicad_pcb]
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2026-01-22 fix some small td-hv issues
    [flyback.kicad_sch]
2026-01-22 swap to cheaper sic mosfet
    [flyback.kicad_sch]
2026-01-22 swap to cheaper capacitor
    [flyback.kicad_sch]
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

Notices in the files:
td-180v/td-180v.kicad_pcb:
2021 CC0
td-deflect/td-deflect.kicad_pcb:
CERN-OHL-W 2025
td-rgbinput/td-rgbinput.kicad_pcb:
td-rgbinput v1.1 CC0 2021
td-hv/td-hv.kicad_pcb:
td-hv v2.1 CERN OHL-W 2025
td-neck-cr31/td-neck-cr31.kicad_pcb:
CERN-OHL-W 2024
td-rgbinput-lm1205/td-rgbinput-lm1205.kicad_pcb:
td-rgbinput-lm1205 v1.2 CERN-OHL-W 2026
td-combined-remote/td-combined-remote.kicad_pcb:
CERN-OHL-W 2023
